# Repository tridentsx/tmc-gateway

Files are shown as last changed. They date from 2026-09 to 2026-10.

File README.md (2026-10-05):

# tmc-gateway

A PoE Ethernet- and USB-attached GPIB instrument gateway: one small board,
plugged directly into an instrument's IEEE-488 connector, that exposes it to
the network and to USB simultaneously.

## What it does

One RP2354A-based adapter per GPIB instrument, acting as that instrument's
GPIB System Controller and Controller-in-Charge, reachable over:

- **[HiSLIP][hislip]** (IVI-6.1) over Ethernet/PoE, TCP port 4880
- **USBTMC** and its **USB488** subclass over USB
- Raw SCPI over TCP port 5025 (planned; not yet built)

The central architectural rule, carried over from the design specification:

> HiSLIP, USBTMC/USB488, raw SCPI, and any future management interface never
> manipulate GPIB pins directly. They submit operations to one serialized
> GPIB engine.

That engine is [`gpib.Instrument`](gpib/instrument.go) — see
[Software](#software) below.

## Hardware

| | |
|---|---|
| MCU | RP2354A (RP2350 family, 2 MB integrated flash), QFN-60 |
| Ethernet | WIZnet W5500 (SPI) |
| PoE | DP9900LPB isolated PD module, IEEE 802.3af, with a USB-C alternate power path (§30.1) |
| GPIB transceivers | TI SN75160B (data bus) + SN75161B (management bus) |
| GPIB connector | 24-pin IEEE-488, NorComp 112-024-113R001 |
| USB | USB-C (USBTMC/USB488, plus alternate power input) |

Board is 62×68 mm, 4 copper layers. Schematic is complete and verified —
confirmed by actually running the checks below, not just citing an old note:
`scripts/netlist-check.py` reports **124 checks, 0 failures**; ERC reports 3
`pin_not_driven` errors, all on W5500 (`U2`) SPI inputs (`SCS`/`SCLK`/`MOSI`)
flagged because the driving RP2354A pins are bidirectional across a
hierarchical sheet link — a severity-policy question, not a wiring defect.
PCB has all 93 footprints placed but is **not yet routed**.

- [`docs/design-spec.md`](docs/design-spec.md) — the master design
  specification. One document by design: Part I is the HiSLIP library
  ([tridentsx/hislip][hislip], developed in that separate repository), Part
  II is this hardware, Part III is this firmware, and Parts IV–VII
  (milestones, acceptance criteria, design decisions, risk register) span
  all three. Source comments in `hislip` cite it by section, e.g. "§5.1".
- [`docs/netlist-spec.md`](docs/netlist-spec.md) / [`docs/netlist-spec.nets`](docs/netlist-spec.nets) —
  the canonical net table `scripts/netlist-check.py` verifies the exported
  schematic netlist against.
- [`docs/rp2354a-pinmap.md`](docs/rp2354a-pinmap.md) — the RP2354A GPIO
  assignment: 8 data lines and the DAV/NDAC/NRFD handshake lines suggested
  for PIO, ATN/SRQ/REN/IFC/EOI as plain GPIO, SPI0 to the W5500.

## Software

```text
gpib/            the Instrument abstraction every front end drives (no
                  firmware, no bus driver -- just the interface)
hislipfront/      adapts gpib.Instrument to tridentsx/hislip's server.Device
usbtmcfront/      adapts gpib.Instrument to USBTMC/USB488 Bulk-OUT messages
usbep/            portable, unit-tested USB packet reassembly (host->device)
                  and chunking (device->host) usbtmcfront's messages ride on
cmd/firmware/     the real (skeleton) RP2354A firmware entry point --
                  tinygo-only, gated by the "tinygo" build tag
cmd/tinygocheck/  not firmware -- exists so `just tinygo` has a real main
                  package to build and link, exercising gpib/hislipfront/
                  usbtmcfront together under mainline go's dependency
                  graph but a real tinygo build
cmd/debugconsole/ host-side only (plain go build, no tinygo tag): a
                  terminal UI for cmd/firmware's CDC debug console
```

`gpib.Instrument` is deliberately not a copy of `hislip/server.Device`,
despite both stating the identical "must not know it's GPIB" principle:
`RemoteEnable`, `LocalLockout`, and `GoToLocal` are three separate methods
here, because USB488's own control requests (`REN_CONTROL`, `GO_TO_LOCAL`,
`LOCAL_LOCKOUT`) are three separate requests, not HiSLIP's one combined
`RemoteLocal(mode)` call. Both front ends translate onto the same granular
primitives instead of one needing to reconstruct a combined mode it never
actually received.

### Status

| Piece | State |
|---|---|
| `gpib.Instrument` abstraction | Defined |
| `hislipfront` (HiSLIP → `gpib.Instrument`) | Implemented, unit-tested |
| `usbtmcfront` (USBTMC/USB488 → `gpib.Instrument`) | Core Bulk-OUT dispatch implemented, unit-tested — see scope below |
| `usbep` (USB packet reassembly/chunking) | Implemented, unit-tested — real edge cases (exact-multiple-of-packet-size, empty message, byte-at-a-time feed) |
| `cmd/firmware` (real USB descriptor + endpoint wiring) | Skeleton exists and **actually builds**: `tinygo build -target=pico2` produces a real, well-formed flashable UF2. Backed by a stub `gpib.Instrument` — no real GPIB bus driver yet. **Verified on real hardware** (a W5500-EVB-Pico2, RP2350): descriptor enumerates exactly as designed, and a real USBTMC `RequestDevDepMsgIn` round trip over EP3 OUT/IN produces a correctly encoded response — see below. |
| GPIB bus driver (the concrete `gpib.Instrument`) | Not started |
| Raw SCPI front end | Not started |

Real, load-bearing constraints found by reading TinyGo 0.42.0's actual
`machine/usb` source (not assumed): it hardcodes a **maximum of 3 USB
interfaces total** (a fixed-size array, not a slice), so a USB CDC debug
console (2 interfaces) plus USBTMC (1) exactly fills the budget, with no
room left for anything else on this port. Its outgoing-transfer path does
not itself split a payload larger than one packet across multiple
packets — that's what `usbep.ChunkSender` and `cmd/firmware`'s
`TxHandler` callback do, deliberately, rather than being handled for free
by the framework.

`usbtmcfront`'s stated scope, deliberately not (yet) covered:

- Works on one already-reassembled logical USBTMC message, not raw USB
  transfers — splitting a message across several USB packets and the
  alignment padding USBTMC requires between messages is a transport-framing
  concern for whatever wires it to a real USB endpoint later, the same
  split `hislip/server`'s `Stream` abstraction makes.
- TermChar-based early read termination is decoded but ignored.
- Every control-transfer-based USBTMC/USB488 request — `GET_CAPABILITIES`,
  `INITIATE_CLEAR`, `READ_STATUS_BYTE`, `REN_CONTROL`, `GO_TO_LOCAL`,
  `LOCAL_LOCKOUT`, the abort requests — is not implemented at all; only the
  three Bulk-OUT message types (`DevDepMsgOut`, `RequestDevDepMsgIn`,
  `Trigger`) are.

One real, non-mechanical piece of protocol work is still open before the
bus driver can start: **the real IEEE-488.1 three-wire handshake and
ATN-based addressing.** Nothing here has been verified against real GPIB
hardware yet; treat any bus-timing claim in this repo's history as reasoned
from the spec text, not measured.

### Real-hardware findings (`cmd/firmware`, W5500-EVB-Pico2 / RP2350)

Confirmed by actually flashing and exercising the board, not just building
for it:

- The composed descriptor (CDC debug console + USBTMC/USB488) enumerates
  exactly as designed: 3 interfaces, correct classes (CDC `0x02/0x02/0x01`
  + `0x0A/0x00/0x00`, USBTMC/USB488 `0xFE/0x03/0x01`), correct endpoint
  addresses (`0x03`/`0x83` for the shared USBTMC bulk endpoint).
- A real `RequestDevDepMsgIn` Bulk-OUT write followed by a Bulk-IN read,
  issued from the host with [go-usb][go-usb], round-trips correctly end to
  end through `usbtmcRxHandler` → `usbep.Reassembler` → `usbtmcfront.Handler`
  → `usbep.ChunkSender` → `usbtmcTxHandler`.
- Two real firmware bugs were found and fixed this way, both specific to
  running inside TinyGo's bare-metal USB interrupt handlers, not to the
  protocol logic itself:
  1. `main()` called `machine.EnableCDC` a second time. TinyGo's own
     runtime (`initUSB`, which runs before `main`) already calls it via
     `machine/usb/cdc.EnableUSBCDC` with working handlers; the redundant
     call overwrote them with no-op stubs, silently breaking the debug
     console.
  2. `usbtmcRxHandler` called `println`, `reasm.Feed`, `append`, and
     `usbtmcfront.Handler.HandleBulkOut` directly — all either blocking or
     allocating — from inside a USB interrupt handler. TinyGo's bare-metal
     allocator is not interrupt-safe, so this corrupted state the moment a
     real bulk transfer arrived. The handler now only copies the raw
     packet into a fixed-size ring with a plain array copy (no allocation,
     no blocking); reassembly, dispatch, and response encoding all run in
     the main loop instead, which drains that ring alongside a lightweight
     event log and a heartbeat print, giving an unambiguous liveness signal
     during this kind of debugging.

Built for the *next* real-hardware session, not just this one:
`cmd/firmware`'s CDC console is now interactive (`help`/`version`/
`stats`/`last`/`clear`/`uptime`/`ping`), backed by persistent counters
(packets in, messages reassembled, responses sent, ring overflows, TX
failures) and a bounded hex dump of the last message/response — confirmed
working on real hardware, including the counters incrementing correctly
across a real bulk transfer and `last` showing the exact bytes exchanged.
See `cmd/firmware/debug.go`. `version` reports the exact git commit (plus
`-dirty` if built from an uncommitted tree) and build time, baked in by
`just firmware`'s `-ldflags -X`, so it's possible to confirm which build
is actually running on a given board.

**`cmd/debugconsole`** is the host-side companion: a terminal UI
(`go run ./cmd/debugconsole`, or `just debugconsole`) with a menu of the
commands above plus a free-text box for anything not in that list yet,
so a real-hardware session doesn't mean hand-typing into `screen`/
`picocom`/a pyserial script. Plain `go build`, no `tinygo` tag — runs on
the development machine against an already-flashed, already-connected
board, never on the RP2350 itself.

## Related repositories

- [tridentsx/hislip][hislip] — the HiSLIP protocol/server/client library
  this board's Ethernet-side front end is built on. Intended, once
  finished, to be offered to the `gotmc` organisation.
- [tridentsx/usbtmc][usbtmc] — a fork of [gotmc/usbtmc][gotmc-usbtmc]
  adding a driver backed by [tridentsx/go-usb][go-usb] (no cgo, no
  libusb), intended to be contributed upstream. Its new `wire` subpackage
  is the USBTMC wire-format vocabulary this board's USB-side front end
  will build on.
- [tridentsx/go-usb][go-usb] — the pure-Go USB backend behind the
  `usbtmc` driver above.

## Building what exists today

```sh
go build ./...
go vet ./...
go test ./...
```

```sh
kicad-cli sch export netlist --format kicadsexpr -o build/adapter.net hardware/adapter.kicad_sch
python3 scripts/netlist-check.py docs/netlist-spec.nets build/adapter.net   # expect 131/0
kicad-cli sch erc --severity-error -o /tmp/erc.rpt hardware/adapter.kicad_sch
```

[hislip]: https://github.com/tridentsx/hislip
[usbtmc]: https://github.com/tridentsx/usbtmc
[gotmc-usbtmc]: https://github.com/gotmc/usbtmc
[go-usb]: https://github.com/tridentsx/go-usb

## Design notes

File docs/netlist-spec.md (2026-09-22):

# Netlist Specification: PoE-to-GPIB Adapter

**Status:** Draft — Revision 2 (from-scratch discrete board)
**Date:** 2026-09-21
**Board:** GoTMC HiSLIP PoE-to-GPIB adapter — discrete RP2354A + W5500
**Parent document:** [design-spec.md](design-spec.md), Revision 3, Part II (§25–§33), §41, §64.

---

## 0. Revision 2 changes and divergence from design-spec

Revision 1 specified the board as a carrier for the WIZnet **W5500-EVB-Pico2 module**.
That module is retained only for firmware/protocol development; the production
board is **built from discrete silicon**. This revision replaces the module with a
discrete RP2354A + W5500 design and, in doing so, resolves the supply-sequencing
element differently. The changes below **diverge from design-spec.md Revision 3**
and are proposed for adoption in a design-spec **Revision 4** (§10):

1. **Module → discrete.** design-spec.md §26.1 and stable-decision 11 name the
   W5500-EVB-Pico2 as the platform. Here it is the *development* platform only;
   the product is discrete RP2354A + W5500. The GPIO map, the GPIB physical layer
   and every requirement `R-HW-*` are preserved.
2. **RP2350 → RP2354A.** The QFN-60 RP2354A is pin-identical to the RP2350A but
   adds **2 MB internal stacked flash**, so the external QSPI flash IC, its
   decoupling and the six QSPI nets are removed (RP "Hardware design with RP2350",
   §3: *use RP2354 by omitting the onboard flash and R10*). RP2354 ships on the
   **A4 stepping, which fixes erratum RP2350-E9**; this relaxes `R-HW-030`/`R-HW-031`
   (the Bank-0 input-latch hazard) — external bias is retained for direction
   control, not for E9.
3. **Gating element (decision 1) → all-discrete PG-driven gate.** The load-switch
   IC + supervisor of Revision 1 (TPS22918 + TPS3839) become a **P-FET high-side
   switch + N-FET level-shift driven by a 3V3-good signal** (§3.1). Because the
   board now owns its 3.3 V regulator, "3V3-good" comes from a supervisor on that
   rail rather than a bolt-on watching a module output.
4. **Assembly constraints.** Hand-soldered v1: **passives 0805 minimum**; ICs in
   QFN-60/LQFP/SOIC/SOT/SOT-223 (all hand-solderable). Every BOM line carries an
   **LCSC part number** so symbols/footprints pull via `easyeda2kicad` and the
   same BOM feeds a later JLCPCB PCBA revision.

---

## 1. Purpose and scope

The electrical specification of the discrete adapter board: component list with
LCSC part numbers, the nets, the values that make the board safe, and the trace
from each `R-HW-010`..`R-HW-065` to the parts and nets that implement it.

**Specification depth.** The *decision and safety-critical* subsystems — the
transceiver-rail gate (§3.1), the GPIB safe-state bias (§3.2), the GPIB signal
path, the RP2354↔transceiver GPIO map, the power rails, and the IEEE-488
connector — are specified **pin-precisely** and are machine-checked (§9). The
*standard* MCU and Ethernet support subsystems are specified as **component
blocks with their key nets**, to be entered from two proven references rather than
re-derived pin-by-pin:

- **RP2354A:** Raspberry Pi *"Hardware design with RP2350"* + the **RP2350A Minimal
  KiCad design** (omit flash for RP2354).
- **W5500:** the WIZnet **W5500 datasheet reference schematic (Figure 3)** and a
  W5500 KiCad reference design.

This split matches the parent's own latitude (design-spec.md §31 leaves magnetics/
grounding to EMC, §32 makes protection footprints optional) and the build flow:
the standard subsystems are pulled as reference blocks, the safety-critical parts
are authored here and verified.

RFC 2119 keywords per design-spec.md §1.1. This document defines no new `R-HW-*`
identifiers; it references and implements those of design-spec.md §26–§28.

---

## 2. Architecture

```text
        RJ45 (PoE MagJack J2, 802.3af)
        │  data pairs         centre taps + spare pairs
        │                     │
   Ethernet magnetics    ┌────┴─────┐
        │                │ WIZPoE-P1 │ M1  (isolated 802.3af PD)
   TXOP/TXON/RXIP/RXIN   └────┬─────┘
        │                     │ isolated 5 V
      W5500 U2  ◄── SPI ──►  +5V_POE ───┬─────────────────────┐
        │  (GPIO16-21)                   │                     │
        │                          U5 LDO 5V→3V3          Q1 P-FET gate
      RP2354A U1                        │                (on when 3V3 good)
        │  GPIO0-15 (GPIB)          +3V3 ─┬─ U6 supervisor      │
        │  GPIO26/27 (TE/DC)              │   └── 3V3-good ──► Q2 ──► Q1 gate
        │  USB (J3)                  (IOVDD, W5500, bias)       │
        │                                                  +5V_XCVR
   ┌────┴──────┐                                           │  (gated)
   │           │                                    ┌──────┴──────┐
 U3 SN75160B  U4 SN75161B  ◄── VCC = +5V_XCVR ──────┤             │
 (DIO1-8)     (ATN…NRFD)                            (off until 3V3 good)
   └────┬──────┘
     IEEE-488 J1 → instrument
```

Two rails: `+5V_POE` (always present when powered) and `+3V3` (from U5).
`+5V_XCVR` is `+5V_POE` gated by Q1 on 3V3-good. The adapter is permanently the
GPIB System Controller (design-spec.md §26.5).

---

## 3. Decisions resolved

### 3.1 Decision 1 — supply sequencing, all-discrete (`R-HW-020`..`R-HW-022`, `R-HW-044`)

**Gate the transceiver 5 V rail on 3V3-good, with discrete parts.** Same hazard as
Revision 1: the RP2354 Fault-Tolerant pads tolerate 5.5 V **only while IOVDD is at
3.3 V** (RP2350 datasheet §14.9, `VPIN_FT`). `+3V3`/IOVDD comes up after `+5V_POE`,
so the transceivers must not be powered until `+3V3` is good. The SN75160B/SN75161B
present *"No Loading of Bus When Device Is Powered Down (VCC = 0)"* (SLLS004B/005B),
so an unpowered transceiver also satisfies the primary safe-bus requirement
(`R-HW-044`).

Circuit:

```text
            +5V_POE ──┬───────────────[Q1 S]  AO3401 P-FET
                      │                 │
                    R_G1 100k          [Q1 D]──► +5V_XCVR  (U3/U4 VCC)
                      │                 │
            gate node ┴───────┬─────────┘
                      │      C_G 100nF (soft-start / inrush, R-HW-051)
                    [Q2 D]  2N7002 N-FET
                      │
            3V3-good ─[Q2 G]      [Q2 S]──GND
                │      │
              (U6)    R_G2 100k ──GND   (fail-safe: Q2 off when 3V3-good undriven)
```

| Ref | Part (LCSC) | Role |
|---|---|---|
| **U5** | LDO 5V→3.3V, AP2114H-3.3TRG1, SOT-223 (**C150716**); alt AMS1117-3.3 (**C6186**) | `+5V_POE → +3V3`, ≥1 A ≫ the ~180 mA load (§3.3) |
| **U6** | Supervisor **TPS3839G33DBZR**, SOT-23-3 (**C485802** ✔), `VIT-` = 3.003/**3.08**/3.126 V, `Vhys` 31 mV, **push-pull** active-low RESET | Emits **3V3-good** (RESET high when +3V3 ≥ threshold) |
| **Q1** | AO3401 P-FET, SOT-23 (**C15127**), −30 V, `Vgs(th)` ≈ −1.1 V | High-side switch `+5V_POE → +5V_XCVR` |
| **Q2** | 2N7002 N-FET, SOT-23 (**C8545**) | Level-shifts 3V3-good to the 5 V-referenced Q1 gate; allows full turn-off |
| **R_G1** | 100 kΩ, gate→+5V_POE | Default **off** (Q1 gate pulled to source) |
| **R_G2** | 100 kΩ, Q2 gate→GND | Fail-safe **off** when U6 is unpowered/high-Z |
| **C_G** | 100 nF, gate→+5V_POE (with R_G1) | Controlled turn-on ~10 µs–ms band, inrush limit (`R-HW-051`) |

Chain: **+3V3 ≥ 3.08 V → U6 RESET high → Q2 on → Q1 gate pulled low → Q1 on →
+5V_XCVR live.** When +3V3 is absent U6 is unpowered, `R_G2` holds Q2 off, `R_G1`
holds Q1 off, `+5V_XCVR` is dead — the transceivers cannot drive the FT pads or
the bus. This is the sequencing `R-HW-020` requires, built from a P-FET the way
you asked, with the "3V3-good" threshold (not mere presence) coming from U6.

**U6 = TPS3839G33DBZR (C485802), verified against SBVS193D.** Its `RESET` is
**push-pull**, so `PG_3V3` needs no pull-up and `R_G2` remains the sole fail-safe;
an open-drain supervisor would have required a pull-up whose rail choice is itself
a hazard (a pull-up to +5V would assert 3V3-good with no +3V3 present). `VIT-` =
3.003 / 3.08 / 3.126 V against the AP2114H's ±1.5 % band (3.25–3.35 V) leaves
≈124 mV between `VIT-`max and the rail's minimum, so the gate cannot chatter.

**Defect found while drawing the schematic (2026-09-21): `C_G` must return to
+5V_POE, not to GND.** The machine-readable table in `docs/netlist-spec.nets`
listed `C_G.2` on `GND` while the row above puts C_G "gate→+5V_POE". Those are
not interchangeable. A gate-to-GND capacitor holds the gate near 0 V while
`+5V_POE` rises, so `Vgs` follows the rail down to about −5 V and **Q1 turns on**
during the ramp — powering the transceivers with IOVDD absent, the exact
condition `R-HW-020` exists to prevent. Referenced to the source instead, C_G
holds `Vgs ≈ 0` (off) through the rail's rise and, with `R_G1`, sets the
turn-on ramp. The schematic follows this row; the net table has been corrected
to match, and `scripts/netlist-check.py` now fails if C_G is moved back.

**Consequence for the boot sequence (§41, `R-FW-110`):** the TPS3839 holds RESET
asserted for a further **≈200 ms** after +3V3 crosses `VIT- + Vhys`, so
`+5V_XCVR` — and therefore U3/U4 — is unpowered for roughly the first 200 ms of
board life. Firmware MUST NOT assume the transceivers are powered at reset; this
strengthens rather than weakens `R-HW-020`, but it is a timing fact the firmware
bring-up has to expect.

Why not a single integrated-PG LDO: the clean LCSC part (LM9076, LDO + delayed
reset) is rated **150 mA**, below the ~180 mA the W5500-dominated 3.3 V rail draws,
so a ≥1 A LDO plus a separate supervisor is used. `VIT-` = 3.0–3.08 V is high
enough that IOVDD is effectively 3.3 V for the FT precondition, low enough to
clear the LDO's regulation band. Compatible with the boot sequence (design-spec.md
§41): hardware enforces step 1 before firmware runs (`R-FW-110`).

### 3.2 Decision 2 — safe bus state (`R-HW-040`..`R-HW-044`), unchanged from Rev 1

The SN75161B direction table (SLLS005B): ATN/IFC/REN follow **DC** (driven onto the
bus only when DC = L); DAV/NDAC/NRFD follow **TE**. RP2354 pads come up
high-impedance, so TE and DC are biased externally; the RP2354 A4 stepping fixes
E9, but external bias is still required to define direction when the MCU is not
driving.

**Safe state: `TE = L`, `DC = H`** → SN75160B DIO high-impedance, ATN/IFC/REN
received (not driven). SRQ, NDAC, NRFD are the only lines the SN75161B drives in
this state; SRQ is de-asserted by bias, NDAC/NRFD settle to the benign
not-ready/not-accepted hold (no transfer without a DAV strobe, and DAV is a
receiver here).

| Net | Bias | Result |
|---|---|---|
| `TE`  (U1 GPIO26) | `R_TE` 10 kΩ **→ GND** | TE = L: nothing drives data or DAV |
| `DC`  (U1 GPIO27) | `R_DC` 10 kΩ **→ +3V3** | DC = H: ATN/IFC/REN receive |
| `ATN_T` (GPIO8) | `R_ATN` 10 kΩ **→ +3V3** | de-assert if DC ever = L with MCU idle (`R-HW-041`) |
| `REN_T` (GPIO10)  | `R_REN` 10 kΩ **→ +3V3** | `R-HW-041` |
| `IFC_T` (GPIO11)  | `R_IFC` 10 kΩ **→ +3V3** | `R-HW-041` |
| `SRQ_T` (GPIO9) | `R_SRQ` 10 kΩ **→ +3V3** | de-assert the SRQ driven when DC = H |

**Rail discipline (invariant):** every bias references `+3V3` or `GND`, **never
`+5V`**. TE/DC land on GPIO26/27, which are not fault-tolerant, so a 5 V pull-up is
forbidden (design-spec.md §64); the FT-pin pull-ups also stay on +3V3 so no 5 V is
injected during the IOVDD-absent window.

### 3.3 Decision 3 — power budget (`R-HW-050`..`R-HW-053`)

**3.3 V rail (from U5):**

| Load | Current | Source |
|---|---:|---|
| W5500 @100 Mbit/s TX | 132 mA | W5500 datasheet |
| RP2354A dual-core @150 MHz + PIO + SPI + IO | 30 mA | RP2350 datasheet Table 1446 + margin |
| Board housekeeping (status LED, U6, crystals) | 15 mA | est. |
| Safe-state bias (DC + ATN/REN/IFC/SRQ + CFG ≈ 6 × 0.33 mA) | 2 mA | computed |
| **+3V3 subtotal** | **≈ 180 mA** → 0.59 W | |

**U5 dissipation:** (5 − 3.3) × 0.18 ≈ **0.31 W** in the LDO — fine in SOT-223, but
it is the board's hot spot and is included in the thermal check (`R-HW-053`).

**5 V transceiver rail `+5V_XCVR`** (gated): SN75160B `ICC` 110 mA + SN75161B `ICC`
110 mA + bus-termination worst case ~30 mA ≈ **250 mA → 1.25 W** (SLLS004B/005B).

**Total on `+5V_POE`:** module-less, so: U5 input (0.59 W ÷ ~0.9 ≈ 0.15 A at 5 V
after LDO — an LDO is ~66 % efficient here, so ≈ 0.18 A) + `+5V_XCVR` 0.25 A +
housekeeping ≈ **≈ 0.44 A → 2.2 W**, +25 % margin ≈ **0.55 A → 2.75 W**.

**Against the sources:** WIZPoE-P1 rated 5 V / **8 W typ (≈ 1.6 A)** → load is
28–34 %, margin > 3×. 802.3af guarantees **12.95 W at the PD**; input ≈ 2.2 W ÷ 0.80
≈ **2.75 W** typical (≈ 3.4 W worst-case) → **Class 1 (≤ 3.84 W)**, margin > 3×.
M1's class is programmable, so the board can declare Class 1 and a PSE reserves
only that much rather than a module's full rating.

**Inrush / bulk (`R-HW-051`):** `C_BULK` 47 µF on `+5V_POE` (hold-up through the
`+5V_XCVR` turn-on step); `+5V_XCVR` local bulk 2 × 4.7 µF + 2 × 100 nF, charged
through the `R_G1`·`C_G` gate ramp on Q1 (soft-start), inrush a few tens of mA.
`R-HW-052` replaces these with measured figures on the prototype.

---

## 4. Component list (BOM)

Passives are **0805 minimum**, X7R/C0G, 1 % (R) / 10 % (C) unless noted. LCSC
numbers marked *(verify)* are the best current candidate to confirm on LCSC before
release; representative 0805 basic-part numbers are given for common values.

### 4.1 Active / key components

| Ref | Part | Package | LCSC | Function |
|---|---|---|---|---|
| **U1** | Raspberry Pi **RP2354A** | QFN-60 | **C41378174** | MCU, 2 MB internal flash (no external QSPI) |
| **U2** | WIZnet **W5500** | LQFP-48 | **C32843** ✔ | Hardwired TCP/IP + 10/100 PHY |
| **U3** | TI **SN75160BDW** | SOIC-20 | *(number to source)* | GPIB data transceiver (DIO1–8). Symbol/footprint from KiCad stock: `Interface:SN75160BDW` + `Package_SO:SOIC-20W_7.5x12.8mm_P1.27mm` |
| **U4** | TI **SN75161BDW** | SOIC-20 | **C139410** ✔ | GPIB management transceiver (C139410 is the **161**, confirmed) |
| **U5** | Diodes **AP2114H-3.3TRG1** | SOT-223 | **C150716** ✔ | 5 V→3.3 V LDO, 1 A (alt AMS1117-3.3, **C6186** ✔). **Not C166063** — see §4.3 |
| **U6** | TI **TPS3839G33DBZR** (`VIT-` 3.08 V typ, push-pull) | SOT-23-3 | **C485802** ✔ | 3V3-good signal. Pins: 1 GND, 2 `RESET`, 3 VDD |
| **Q1** | Alpha&Omega **AO3401** | SOT-23 | **C15127** | P-FET high-side gate |
| **Q2** | **2N7002** | SOT-23 | **C8545** | N-FET level-shift |
| **M1** | PoE PD front-end — SDAPO **DP9900LPB-5V1.4A**, isolated PD module + DC-DC, 36–57 V in, 5 V/1.4 A (7 W) out, 1500 V I/O isolation, **programmable power class**. Bridges are **not** included — see D_BR1/D_BR2 | SMD, **21.2 × 13.9 × 8.0 mm** (verified from the part's 3D model) | **C53065982** ✔ *(specs/geometry verified; stock not verified)* | Isolated 802.3af PD → +5V_POE. Pins: 1 +VDC → +5V_POE, 2 −VDC → GND, 3 ADJ (unused), 4 VIN+, 5 VIN− ← bridge outputs. Dimension- and pin-compatible with **Silvertel Ag9905-LPB** (second source) |
| **D_BR1, D_BR2** | MCC **MB6S-TP** bridge rectifier ×2, 600 V / 0.5 A | MBS (SOIC-4), 4.7 × 4.0 × 2.5 mm | **C85619** ✔ | Rectify each pair set for M1's VIN±: D_BR1 = Alternative A (RJ45 1&2, 3&6 taps), D_BR2 = Alternative B (4&5, 7&8). ~60 mA at 48 V against a 0.5 A rating; 600 V PIV is generous over 57 V + surge |
| **J1** | **NorComp 112-024-113R001** — Centronics-24 (IEEE-488) **male**, right-angle PCB; alt FUYCONN FUY57109A | 24-way THT, 2 × 12 on 2.16 mm pitch, 4.29 mm rows, 2 × 3.1 mm holes on 46.8 mm | *(distributor; not an LCSC line)* | Instrument connector, **direct plug** into the instrument's female port. Symbol `Connector_GPIB:Conn_GPIB_L-com_CIB24SRA` (pinout is gender-independent); footprint `adapter:CONN_112-024-113R001_NRC`, **verified** — see §4.4 item 2 |
| **J2** | PoE MagJack — candidate **USAKRO DGUK411Q211DB2A1DP2** (2.5G PoE+, 4-pair, 4 × CT + VC1–VC4) | RJ45 TH int. magnetics | **C19725138** ⚠ *(pin function unconfirmed — see §4.4)* | Ethernet + PoE tap |
| **J3** | USB-C receptacle **TYPE-C-31-M-12** | 16-pin SMD | **C165948** | USB (flash + CDC diag) |
| **X1** | **12 MHz** crystal, Abracon **ABM8-272-T3** (RP-recommended), 10 pF, ≤50 Ω ESR | 3.2×2.5 mm | *(verify; LCSC 12 MHz alt)* | RP2354 clock |
| **X2** | **25 MHz** crystal (W5500), ±30 ppm | 3.2×2.5 mm | *(verify)* | W5500 clock |
| **L1** | Abracon **AOTA-B201610S3R3-101-T**, 3.3 µH, shielded, polarity dot | 0806 | *(verify)* | RP2354 core SMPS inductor |

### 4.2 Passives and discretes (0805 minimum)

**Designator convention.** KiCad treats a reference with no trailing digit as
*unannotated*, and an annotate pass in eeschema would silently rename such parts
— breaking the correspondence between the schematic and this document. Every
designator therefore carries a numeric suffix in the schematic and in
`netlist-spec.nets`: `R_TE1`, `C_G1`, `TP_5V1`, `C_U3a1`, and so on. This
section's tables name the parts without the suffix for readability; the suffixed
form is the authoritative one.

| Ref(s) | Value | LCSC (representative) | Purpose |
|---|---|---|---|
| C_BULK | 47 µF, 16 V | C2011903 ✘ *(is a 16 MHz oscillator — reselect)* | +5V_POE bulk / hold-up (`R-HW-051`) |
| C_U3a, C_U4a | 100 nF ×2 | C49678 ✔ | VCC bypass at U3/U4 |
| C_U3b, C_U4b | 4.7 µF ×2 | C1779 ✔ (0805) | +5V_XCVR local bulk |
| C6, C7, C9 | 4.7 µF ×3 | C1779 ✔ | RP2354 core reg in/out (per RP minimal) |
| C_1V2 | 4.7 µF | C1779 ✔ | W5500 1V2O (datasheet-mandated) |
| C_ANA | 10 nF | C1710 ✔ (0805) | W5500 analog cap (datasheet-mandated) |
| C_MCU × n | 100 nF each | C49678 ✔ | RP2354 IOVDD/DVDD decoupling (per RP minimal) |
| C_ETH × n | 100 nF each | C49678 ✔ | W5500 AVDD/VDD decoupling |
| C_X1a/b | 15 pF ×2 | C1644 ⚠ *(value right, **0603** — breaks the 0805 rule)* | X1 (12 MHz) load caps |
| C_X2a/b | per X2 spec | *(verify)* | X2 (25 MHz) load caps |
| C_3V3 | 1 µF | C28323 ✔ | +3V3 local bypass |
| C_LDO | 1 µF in + 1 µF out | C28323 ✔ | U5 in/out (AP2114H) |
| RSET | 12.4 kΩ 1% | C218478 ✘ *(is 287 Ω — reselect)* | W5500 EXRES1 → AGND |
| R_G1 | 100 kΩ | C149161 ✘ *(no such part — reselect)* | Q1 gate pull-up → +5V_POE |
| R_G2 | 100 kΩ | C149161 ✘ *(no such part — reselect)* | Q2 gate pull-down → GND |
| C_G | 100 nF | C49678 ✔ | Q1 gate soft-start |
| R_TE | 10 kΩ | C17414 ✔ | TE pull-down → GND (`R-HW-040`) |
| R_DC | 10 kΩ | C17414 ✔ | DC pull-up → +3V3 (`R-HW-040`) |
| R_ATN,R_REN,R_IFC,R_SRQ | 10 kΩ ×4 | C17414 ✔ | de-assert bias → +3V3 (`R-HW-040`/`041`) |
| R_CFG | 10 kΩ | C17414 ✔ | CFG (GPIO28) defined state (`R-HW-065`) |
| R_CC1, R_CC2 | 5.1 kΩ ×2 | C23186 ⚠ *(value right, **0603**)* | USB-C CC pull-downs (device role) |
| R_PE | 0 Ω (opt pad) | C17168 ⚠ *(value right, **0402**)* | U3 PE→+5V_XCVR (3-state, §29) |
| R_RUN, R_BOOT | 10 kΩ ×2 | C17414 ✔ | RUN pull-up / BOOTSEL (per RP minimal) |
| SW_RUN, SW_BOOT | tact | *(verify)* | reset / BOOTSEL buttons |
| LED1 (+R_LED) | status LED + 1 kΩ | C2286 ⚠ *(**0603** LED)* / C17513 ✔ | status LED (`R-HW-064`), on a GPIO |
| R_SH / C_SH | 0 Ω / RC (opt) | C17168 ⚠ *(**0402**)* | connector shield → chassis (§31) |
| TP_* | test pads | — | TE,DC,ATN,DAV,NRFD,NDAC,SRQ,IFC,5V,3V3,GND (§32) |

### 4.3 LCSC verification log (2026-09-21)

Every number above was queried against the EasyEDA/LCSC component API before any
symbol was pulled; `✔` means the API returned the expected manufacturer part and
an 0805-or-larger package, `⚠` the right value in a package smaller than the
§0.4 hand-assembly rule, `✘` a number that does not describe the intended part at
all. Seven of the twenty checked were wrong, so **no number in this document may
be trusted without a query** — including the ones that were never marked *(verify)*.

| Number | Spec claimed | API returned | Verdict |
|---|---|---|---|
| C41378174 | RP2354A | RP2354A, QFN-60 | ✔ |
| C32843 | W5500 | W5500, LQFP-48 | ✔ |
| C139410 | SN75161BDW (160/161 unsure) | SN75161BDW, SOIC-20 | ✔ — it is the **161** |
| C166063 | AP2114H-3.3TRG1 | **SK1117-1.5** (SHIKUES), a **1.5 V** LDO | ✘ **wrong rail** |
| C150716 | — | AP2114H-3.3TRG1 (Diodes), SOT-223 | ✔ **use this for U5** |
| C53065982 | — | DP9900LPB-5V1.4A (SDAPO), 5 V/1.4 A PD module, 21.2 × 13.9 × **8.0 mm** from its 3D model | ✔ **use this for M1** |
| C53065979 | — | DP9900MTB-5V1.8A, same footprint, 13.4 mm tall | ⚠ rejected on height |
| C53065972 | — | DP1425-5V1.8A, bridges included, single-row edge-mount SIP | ⚠ rejected: height undocumented |
| C85619 | — | MB6S-TP (MCC), 600 V/0.5 A bridge, MBS 4.7 × 4.0 mm | ✔ **use this for D_BR1/D_BR2** |
| C6186 | AMS1117-3.3 (alt) | AMS1117-3.3, SOT-223 | ✔ |
| C15127 | AO3401 | AO3401A, SOT-23 | ✔ |
| C8545 | 2N7002 | 2N7002, SOT-23 | ✔ |
| C165948 | TYPE-C-31-M-12 | TYPE-C-31-M-12 | ✔ |
| C7217089 | AR11-3757I MagJack | *not in catalogue* | ✘ |
| C485802 | — | TPS3839G33DBZR (TI), SOT-23-3, `VIT-` 3.08 V, push-pull | ✔ **use this for U6** |
| C19725138 | — | DGUK411Q211DB2A1DP2 (USAKRO), 2.5G PoE+ RJ45 TH, 22 pins | ⚠ **J2 candidate**, pinout unconfirmed |
| C49678 | 100 nF | CC0805KRX7R9BB104, 0805 | ✔ |
| C17414 | 10 kΩ | 0805W8F1002T5E, 0805 1 % | ✔ |
| C1779 | 4.7 µF | CL21A475KAQNNNE, 0805 | ✔ |
| C28323 | 1 µF | CL21B105KBFNNNE, 0805 | ✔ |
| C1710 | 10 nF | CL21B103KBANNNC, 0805 | ✔ |
| C17513 | 1 kΩ | 0805W8F1001T5E, 0805 | ✔ |
| C23186 | 5.1 kΩ | 0603WAF5101T5E, **0603** | ⚠ |
| C17168 | 0 Ω | 0402WGF0000TCE, **0402** | ⚠ |
| C1644 | 15 pF | CL10C150JB8NNNC, **0603** | ⚠ |
| C2286 | status LED | KT-0603R, **0603** | ⚠ |
| C218478 | 12.4 kΩ 1 % | ARG05FTC2870 = **287 Ω** | ✘ |
| C2011903 | 47 µF 16 V | 653L16003C2T = **16 MHz oscillator** | ✘ |
| C149161 | 100 kΩ | *not found* | ✘ |

**The C166063 error was the dangerous one.** It was recorded as confirmed, not
*(verify)*, and it would have put a **1.5 V** regulator on the rail that feeds
IOVDD, every bias network and the W5500 — the board would not run, and the
`R-HW-020` gate precondition ("+3V3 ≥ 3.08 V") could never be met. Correct part:
**C150716**.

Still to source before the BOM is releasable: U3 (SN75160BDW), J1 (IEEE-488
connector), X1/X2 (12 MHz / 25 MHz crystals), L1 (3.3 µH), C_BULK (47 µF), RSET
(12.4 kΩ 1 %), R_G1/R_G2 (100 kΩ), and 0805 replacements for the four `⚠` parts.
The schematic can be authored ahead of these: U3 has a stock KiCad symbol, J1 has
an authored one, and the rest are generic `Device:` symbols whose footprint
assignment is the only thing that waits on the number.

### 4.4 Open hardware questions (blocking the Ethernet/PoE sheet)

**1. The PD front-end is now specified: SDAPO DP9900LPB-5V1.4A (C53065982) plus
two MB6S bridges (C85619).** Revision 2 delegated the whole 802.3af
powered-device function to the WIZPoE-P1, a WIZnet accessory for WIZnet's own
boards, now withdrawn. The replacement covers every function the standard
requires of a PD, but it is worth being precise about where each one lives,
because the module's own marketing is easy to misread:

- **inside M1**: the 25 kΩ detection signature, the classification current
  signature (programmable class), inrush and operating current limit, the
  hot-swap switch, 1500 V galvanic isolation, and the 48 V → 5 V conversion;
- **outside M1, ours to provide**: the **bridge rectifiers**. The DP9900 series
  presents `VIN+`/`VIN−` as *Direct Input* pins that, per its pin table,
  "connect to the … output of the input bridge rectifiers" — i.e. the bridges
  are external. D_BR1 and D_BR2 supply them, one per pair set, so the board
  accepts Alternative A and B feeds in either polarity.

The isolation living inside M1 is not an optimisation: the IEEE-488 shell bonds
to the instrument chassis and J3 is a second external interface, so the barrier
must sit upstream of board ground.

**Why this part.** It was selected on **height**, which is what a dongle
enclosure actually constrains — not footprint area, as an earlier revision of
this section wrongly implied. Verified from the part's own 3D model at
**21.2 × 13.9 × 8.0 mm**, matching Silvertel's published 21 × 14 × 8 mm for the
equivalent Ag9900LPB. The alternatives measured or reported as: DP9900MTB
(C53065979) 21.2 × 13.9 × **13.4 mm**, same footprint, 5.4 mm taller; DP1425
(C53065972) bridges-included but a single-row edge-mount SIP whose height is
documented only as a drawing, hence unverifiable and plausibly 15–25 mm. 8.0 mm
is about the height of the IEEE-488 connector body, so M1 fits under the same lid
rather than setting it.

Being dimensionally and functionally interchangeable with **Silvertel
Ag9905-LPB** gives a second source, which matters on a board that already
carries an EOL risk for U3/U4 (design-spec.md §67, R24).

7 W against the §3.3 load of 2.75 W is 2.5× margin, and the programmable class
means the board can declare Class 1 rather than reserving a PSE's full budget.

**The documented path to smaller and cheaper** is MPS **MP8017**: an 802.3af PD
interface (detection, classification, inrush and operating current limit, 100 V
hot-swap MOSFET) *plus* an active-clamp primary-side-regulation flyback
controller in a QFN-19 3 × 4 mm, with an MPS 5 V reference design
(EVL8017-L-00B). It is the right answer for a volume revision or if 8 mm is ever
too tall, at the cost of owning the transformer selection, the isolation-barrier
layout and the EMC — risk that buys nothing on a v1 whose purpose is proving the
protocol stack.

**Stock is unverified** for both M1 and the bridges: specifications, geometry and
pinouts were read from datasheets, the LCSC/EasyEDA catalogue and the parts' own
3D models, none of which report inventory. Confirm availability before release.

**2. J1's gender is settled: male, and the adapter is a direct-plug dongle.**
J1 is a **FUYCONN FUY57109A**, Centronics-24 male, right-angle PCB mount, which
plugs straight into the instrument's female GPIB port — the form the original
specification intended and the one commercial GPIB-Ethernet adapters take.

Two consequences follow.

*The vendored footprint cannot be used.* `gpib-kicad-library` supplies L-com
**female** receptacles only. Male and female pad numbering are mirror images, so
building on the female pattern would put every DIO line on the wrong pin — the
one error on this sheet that produces a board which looks right and is
electrically scrambled. J1's footprint is therefore **deliberately unassigned**
until FUYCONN's PCB drawing for this part is in hand. The symbol is unaffected:
the IEEE-488 pinout is gender-independent, and it was cross-checked against §5.4
pin for pin.

*Height is the binding enclosure constraint.* A dongle hangs off the instrument's
port, so the lid clearance is set by the tallest part, not by board area. This is
what selected the 8.0 mm DP9900LPB over the 13.4 mm MTB in item 1.

**J1's footprint is now resolved: `adapter:CONN_112-024-113R001_NRC`.** The part is
a **NorComp 112-024-113R001**, the male alternate this specification already
named, and its vendor-supplied KiCad footprint was measured before adoption:

- 24 through-hole pads, 0.99 mm drill, **pins 1–12 on one row and 13–24 on the
  other** — the IEEE-488 row split, not a header's alternating order;
- **2.16 mm** pitch along each row, rows **4.29 mm** apart;
- two non-plated **3.1 mm** mounting holes at x = −11.52 and +35.28, a
  **46.8 mm** span;
- courtyard present; no 3D model supplied.

Those numbers agree with the vendored L-com female footprint, and the two are
**mirror images** of each other: the NorComp male runs pin 1 → 12 in increasing x
with holes at −11.52/+35.28, the L-com female runs 1 → 12 in decreasing x with
holes at −35.28/+11.52. Two vendors, two independently sourced files, agreeing on
the grid and differing exactly by the mirror the gender change predicts. That is
the check that the earlier revision of this section said was required, and it is
now satisfied by measurement rather than assumption.

The generic `PinHeader_2x12_P2.54mm_Horizontal` placeholder that occupied this
slot has been replaced; nothing in the design references it any more.

FUYCONN FUY57109A remains recorded as the alternate, but **its footprint has not
been verified** — the vendor's PCB drawing was not obtainable — so substituting
it requires repeating the measurement above.

**3. J2 centre-tap mapping — CLOSED 2026-09-22 by documentation.**

Resolved from the connector's own datasheet (LCSC C19725138, Dongguan Usakro,
sheet 3) and the WIZnet WIZPoE-P1 datasheet; no ring-out needed.

The connector drawing labels its two columns "PCB SIDE TO PHY" and "CABLE SIDE",
and the cable side carries `J1 TX1+` .. `J8 TX4-`, i.e. the eight RJ45 contacts.
The turns-ratio notes give every transformer as `1CT:1CT`, so both windings have
centre taps: the four `CT` pins (1, 6, 7, 12) are the **PHY-side** taps and
`VC1`-`VC4` (13-16) are the **cable-side** taps, which is where PoE is extracted.
Note 8 confirms the part is 802.3at magnetics "for PSE or PD applications", rated
720 mA / 57 V DC continuous.

The WIZPoE-P1 datasheet pin table fixes the Alternative mapping outright:

| Module pin | Connects to the centre tap of | Alternative |
|---|---|---|
| `VC1 (+)` | the pair on RJ45 **1 & 2** | A |
| `VC1 (-)` | the pair on RJ45 **3 & 6** | A |
| `VC2 (+)` | the pair on RJ45 **4 & 5** | B |
| `VC2 (-)` | the pair on RJ45 **7 & 8** | B |

each "not polarity sensitive" and feeding the +/- of an input bridge rectifier.
This is why `D_BR1`/`D_BR2` exist and why `POE_VIN_N` is not ground: neither the
Alternative nor the polarity is known in advance. Our `POE_TAP_A1/A2` therefore
take `VC1`/`VC2` and `POE_TAP_B1/B2` take `VC3`/`VC4`, as wired.

The Bob Smith network (`4*22nF`, `4*75R`, `1000pF/2kV` to `SHIELD`) is internal to
this connector - confirmed against the drawing - so no external termination or
shield capacitor is fitted. The series 22 nF per tap is what stops the two
pair-sets being DC-coupled through the common 75 R node, which is what makes the
`VC` pins usable for PoE at all.

**This is convergent evidence, not the part's own datasheet**, so it is not yet
sufficient to wire 48 V. Two things remain unproven: the `CT`/`VC` split itself,
and *which* `VC` belongs to *which* RJ45 pair — the latter matters because each
bridge must see the two taps of one Alternative (A = pairs 1&2 and 3&6, B = pairs
4&5 and 7&8). Mixing a pair-set across bridges is a wiring defect.

**Ring-out procedure (decisive, needs one sample and an ohmmeter).** Each tap sits
at the electrical centre of one transformer winding, so it reads a fraction of an
ohm to *both* ends of that winding and open to the other side of the barrier:

- a **cable-side** tap reads ≈0.5–2 Ω to both RJ45 contacts of its pair (e.g.
  contacts 1 and 2) and open to that pair's `TD±` pins;
- a **PHY-side** tap reads ≈0.5–2 Ω to both `TD+` and `TD−` of its pair and open
  to the RJ45 contacts.

The same measurement also yields the pair mapping, since it identifies which RJ45
contacts each tap belongs to. Record the result here before the Ethernet sheet is
drawn.

**Safety rule regardless of outcome:** the PHY-side taps must never connect to the
PoE feed. They sit on the isolated side referenced to board ground, and bridging
them to the cable-side taps would short across the isolation barrier that M1
provides — defeating the property that keeps 48 V off the instrument chassis
through the IEEE-488 shell.

One more property of this jack worth carrying forward: it is a 4-pair 2.5G part
while the W5500 is 10/100. The extra pairs are harmless and in fact allow both
Alternative A and B to be tapped, but the magnetics' open-circuit inductance
should be checked against the W5500's requirement when §5.6 is entered.

---

### 4.5 Silent-failure modes observed in KiCad 10 / Konnect (2026-09-22)

Three defects in this session were invisible in the schematic editor's normal
feedback and were caught only by an explicit check. Each is a class of mistake
that produces a plausible-looking sheet and a wrong netlist, so each is recorded
with the check that detects it.

**1. Wires that miss sheet pins by a grid snap.** `import_sheet_pins` places
pins at half-grid positions (x = 150.00, y = 42.54), while wire endpoints are
snapped to the 1.27 mm grid. A wire drawn to a pin's exact coordinates therefore
lands at (149.86, 41.91) and does not connect. Nothing complains: the wires are
drawn, they simply conduct nothing, and the two sheets stay on separate nets with
identical net names. Detected by `validate_wire_connections` (36 floating
endpoints) and by two nets named `TE` in one exported netlist. Fixed by placing
each sheet's origin on the 1.27 mm grid, which makes every pin grid-aligned
because the pin offsets are multiples of 2.54 mm.

**2. Sheet pins outside the sheet outline are silently merged.** `import_sheet_pins`
stacks new pins below the existing ones without growing the sheet box. Six SPI
pins imported onto a 55 mm-tall block put the last three at y = 176.53, 179.07
and 181.61 against a bottom edge at 175.65. KiCad's netlister collapsed all
three into one net: `ETH_MOSI` and `ETH_RSTn` disappeared and `ETH_INTn` carried
GPIO19, GPIO20 and GPIO21 together — three SPI signals shorted. Konnect's own
connectivity model disagreed with KiCad throughout, reporting the three nets as
correctly separate, so the schematic *looked* right from inside the tool that
drew it. Detected by the netlist gate. Fixed by enlarging the sheet block to
contain every pin. **Check pin extents against the block after every
`import_sheet_pins` call.**

**3. Duplicate `#PWR` designators across sheets.** `add_power_symbol` numbers
`#PWR` references per sheet, so a power symbol added to a second sheet reuses
`#PWR001`. The only symptom is `kicad-cli`'s generic "schematic has annotation
errors" warning on the *root* export; each sheet exports cleanly on its own, ERC
reports nothing, and `annotate_schematic` reports zero unannotated symbols
because it does not detect duplicates spread across sheets. Ruled out before
finding it: unannotated instances, reference-prefix mismatches (confirmed
irrelevant by aligning every prefix on a scratch copy — the warning persisted),
and malformed instance paths (the `/<root-uuid>/<sheet-uuid>` form is correct).
Located by bisection: removing either of two sheets cleared the warning, which
is the signature of a duplicate pair. Detect with a cross-sheet scan of
`(reference "...")` outside the `lib_symbols` block; renumber the later sheet's
symbols.

## 5. Net list

Decision/safety subsystems are pin-precise; MCU/ETH support blocks cite their
reference. Pins are `REF.pin`; U1/U2 signal pins are named by function/GPIO as they
appear in the pulled `easyeda2kicad` symbols.

### 5.1 Power and gate nets (pin-precise)

| Net | Members | Safety |
|---|---|---|
| `+5V_POE` | M1.OUT, U5.IN, Q1.S, R_G1.a, C_BULK.+, C_LDOin.+, TP_5V | WIZPoE-P1 output |
| `+3V3` | U5.OUT, U1.IOVDD(×n), U1.VREG_VIN, U2.AVDD/VDD(×n), U6.VDD, RSET pull side n/a, R_DC.a, R_ATN.a, R_REN.a, R_IFC.a, R_SRQ.a, R_CFG.a, R_RUN.a, C_3V3.+, C_LDOout.+, all C_MCU/C_ETH.+, TP_3V3 | IOVDD; **bias reference — never +5 V** |
| `+5V_XCVR` | Q1.D, U3.VCC(20), U4.VCC(20), R_PE.a, C_U3a.+, C_U4a.+, C_U3b.+, C_U4b.+ | **`R-HW-020`/`044`**: off until 3V3-good |
| `GATE` | Q1.G, R_G1.b, C_G.a, Q2.D | Q1 high-side gate node |
| `PG_3V3` | U6.RESET, Q2.G, R_G2.a | **`R-HW-020`**: 3V3-good drives Q2; `R_G2` fail-safe |
| `GND` | U1.GND(×n)+VREG_PGND, U2.AGND(×n), U3.GND(10), U4.GND(10), U5.GND, U6.GND, Q2.S, M1.GND, RSET.b, R_TE.b, R_G2.b, C_G.b, all C.−, J1.18–24, J2 shield/GND, J3.GND/shield, TP_GND | single local ground (design-spec.md §31) |

### 5.2 Control nets (pin-precise)

| Net | Members | Safety |
|---|---|---|
| `TE` | U1.GPIO26, U3.TE(1), U4.TE(1), R_TE.a, TP_TE | **`R-HW-040`** TE=L |
| `DC` | U1.GPIO27, U4.DC(11), R_DC.b, TP_DC | **`R-HW-040`** DC=H |
| `PE` | U3.PE(11), R_PE.b | §29 3-state select |

### 5.3 GPIB data path (U3 SN75160B) — pin-precise, `R-HW-060`

DIO1..DIO8 = GPIO0..GPIO7 (contiguous, DIO1 lowest). U3 pins: TE=1, B1..B8=2..9
(bus), GND=10, PE=11, D8..D1=12..19 (terminal), VCC=20.

| Terminal net | Members | Bus net | Members |
|---|---|---|---|
| DIO1_T | U1.GPIO0, U3.19 | DIO1_B | U3.2, J1.1 |
| DIO2_T | U1.GPIO1, U3.18 | DIO2_B | U3.3, J1.2 |
| DIO3_T | U1.GPIO2, U3.17 | DIO3_B | U3.4, J1.3 |
| DIO4_T | U1.GPIO3, U3.16 | DIO4_B | U3.5, J1.4 |
| DIO5_T | U1.GPIO4, U3.15 | DIO5_B | U3.6, J1.13 |
| DIO6_T | U1.GPIO5, U3.14 | DIO6_B | U3.7, J1.14 |
| DIO7_T | U1.GPIO6, U3.13 | DIO7_B | U3.8, J1.15 |
| DIO8_T | U1.GPIO7, U3.12 | DIO8_B | U3.9, J1.16 |

### 5.4 GPIB management path (U4 SN75161B) — pin-precise, `R-HW-061`

EOI,DAV,NDAC,NRFD = GPIO12–15 (consecutive, one PIO SM). ATN,SRQ,REN,IFC =
GPIO8–11 (Go-driven). U4 pins: TE=1, bus 2–9 (REN2 IFC3 NDAC4 NRFD5 DAV6 EOI7 ATN8
SRQ9), GND=10, DC=11, terminal 12–19 (SRQ12 ATN13 EOI14 DAV15 NRFD16 NDAC17 IFC18
REN19), VCC=20.

| Terminal net | Members | Bus net | Members | Safety |
|---|---|---|---|---|
| ATN_T | U1.GPIO8, U4.13, R_ATN.b | ATN_B | U4.8, J1.11 | `R-HW-041` |
| SRQ_T | U1.GPIO9, U4.12, R_SRQ.b | SRQ_B | U4.9, J1.10 | `R-HW-040` |
| REN_T | U1.GPIO10, U4.19, R_REN.b | REN_B | U4.2, J1.17 | `R-HW-041` |
| IFC_T | U1.GPIO11, U4.18, R_IFC.b | IFC_B | U4.3, J1.9 | `R-HW-041` |
| EOI_T | U1.GPIO12, U4.14 | EOI_B | U4.7, J1.5 | |
| DAV_T | U1.GPIO13, U4.15 | DAV_B | U4.6, J1.6 | |
| NDAC_T | U1.GPIO14, U4.17 | NDAC_B | U4.4, J1.8 | |
| NRFD_T | U1.GPIO15, U4.16 | NRFD_B | U4.5, J1.7 | |

IEEE-488 J1 (Amphenol-57 numbering): 1-4 DIO1-4, 5 EOI, 6 DAV, 7 NRFD, 8 NDAC,
9 IFC, 10 SRQ, 11 ATN, 12 shield, 13-16 DIO5-8, 17 REN, 18-23 twisted-pair returns
(→GND), 24 signal ground (→GND).

### 5.5 MCU support block (U1 RP2354A) — build from RP2350-minimal

Enter per RP "Hardware design with RP2350" / RP2350A Minimal, **omitting the flash
and R10** (RP2354 internal flash). Key nets:

- **Core SMPS:** `U1.VREG_VIN`→+3V3; `U1.VREG_LX`→`L1` 3.3 µH→**`DVDD`** (the
  ≈1.1 V core rail, pins 6/23/39) with `C7` 4.7 µF on DVDD; `U1.VREG_FB`→`DVDD`
  as the sense node; `U1.VREG_PGND`→GND; `U1.VREG_AVDD`→+3V3. L1 orientation per
  RP guidance (the magnetic field couples into C7 if it is fitted the wrong way
  round — "Hardware design with RP2350" §2.5).

  **Corrected 2026-09-21.** Earlier revisions of this line read
  "`VREG_LX`→`L1`→`+3V3` (core node)", which is wrong and destructive: it would
  tie the 3.3 V rail through the inductor to the DVDD pins and feed the ≈1.1 V
  core from 3.3 V. Raspberry Pi's "Hardware design with RP2350" is explicit that
  the regulator produces "a 1.1 V output to supply the DVDD on the chip", with
  L1 and C7 as its output filter and VREG_FB monitoring that output. DVDD is its
  own net and must never be joined to +3V3.
- **Clock:** `X1` 12 MHz between `U1.XIN`/`U1.XOUT`, `C_X1a/b` 15 pF to GND.
- **Decoupling:** 100 nF (`C_MCU`) at every IOVDD/DVDD pin; bulk per minimal.
- **USB:** `U1.USB_DP`/`U1.USB_DM` → `J3` D+/D−.
- **Boot/reset:** `SW_BOOT` on `QSPI_CSn` (+`R_BOOT`); `U1.RUN`←`R_RUN` pull-up to
  +3V3 + `SW_RUN` to GND.
- **Status LED:** `LED1` + `R_LED` on a spare GPIO (e.g. GPIO25); GPIO recorded in
  the board package (`R-HW-064`).
- **SPI to W5500:** GPIO16 MISO, GPIO17 CSn, GPIO18 SCK, GPIO19 MOSI, GPIO20 W5500-RST,
  GPIO21 W5500-INT. Carried off-sheet as hierarchical labels `ETH_MISO`, `ETH_CSn`,
  `ETH_SCK`, `ETH_MOSI`, `ETH_RSTn`, `ETH_INTn` (per the globals-for-rails,
  hierarchical-for-signals rule).
- **SWD debug (added 2026-09-22, not in revision 2).** `U1.SWCLK` and `U1.SWDIO`
  are brought out to test pads `TP_SWCLK1`/`TP_SWDIO1`. The revision-2 net table
  was silent on debug access; a first prototype with no way to attach a probe is
  a false economy, and two pads cost nothing. The alternative — declaring both
  pins `!nc` — was rejected for that reason. Not an SWD header: this is a plug-in
  dongle and the height budget is set by the Centronics connector.
- **USB-C role:** `R_CC1`/`R_CC2` 5k1 from `J3.CC1`/`J3.CC2` to GND (upstream
  facing port / device role). Both `DP1`/`DP2` are tied to `USB_DP` and both
  `DN1`/`DN2` to `USB_DM` so the cable works either way up.

  **`VBUS` is a declared non-connection.** Both VBUS contacts carry `!nc`. The
  board is powered from PoE only; bridging VBUS to `+5V_POE` or `+3V3` would
  backfeed the PoE supply from a host, or the host from the PSE, in violation of
  design-spec §30.1. Bench-powering over USB is deliberately not supported.

**Analogue rail and magnetics, added 2026-09-22 from the WIZnet W5500-EVB-Pico2
reference (SCH-W5500-EVB-Pico2-V100, rev 1.0, 2024-08-01).** The W5500 datasheet
carries no application schematic - 27 figures, none showing the magnetics bias -
so the following is taken from WIZnet's own board, which pairs a W5500 with an
RP2350 and is therefore the same architecture as this design:

- **Separate filtered analogue rail.** `+3V3` feeds ferrite `L2` to make `3V3A`;
  every `AVDD` pin (4, 8, 11, 15, 17, 21) and the magnetics bias run from `3V3A`,
  while `VDD` (28) stays on the unfiltered rail. `PWR_FLAG` marks `3V3A` as driven.
- **Series resistors on the MDI pairs.** `R_TX1`/`R_TX2`/`R_RX1`/`R_RX2`, 3R3 each,
  between the W5500 and the connector (`R15`-`R18` in the reference).
- **Bias/termination.** `R_B1` 10R from `3V3A` to `ETH_BIAS`, decoupled by
  `C_BIAS1` 100n, with `R_T1`-`R_T4` 49R9 from that node to each MDI pin
  (`R28`, `C30`, `R19`-`R22`).
- **Pull-ups the reference does not leave to the internal ones:** `R_RSTP1` 4k7 on
  `ETH_RSTn` and `R_INTP1` 4k7 on `ETH_INTn` (`R12`, `R32`/`R33`).
- **Crystal.** Loads corrected 22p -> **18p** to match the datasheet's stated 18 pF
  load capacitance, plus `R_XF1` 1M feedback across the crystal (`R24`).
- **PHY-side centre taps.** `ETH_TCT` (J2.12, the RJ45 1&2 pair) and `ETH_RCT`
  (J2.6, the 3&6 pair) are AC-grounded through 22n, following `C28`. The taps of
  the two pairs unused at 10/100 (J2.1, J2.7) are declared open.

Deliberately **not** copied from the reference: its jack uses an *external* Bob
Smith network (`C31` 1nF/2kV on the jack's GND pin) whereas ours has it internal,
so no shield capacitor or 75 R network is fitted here.

Independently confirmed by the reference, previously only inferred: the SPI GPIO
map is identical (GPIO16 MISO, 17 CSn, 18 SCK, 19 MOSI, 20 RSTn, 21 INTn);
`EXRES1` 12k4 1% to ground; `TOCAP` 4u7; `VBG` left floating; PMODE[2:0] strapped
high; 25 MHz crystal; a status LED on GPIO25. The reference also brings SWD out on
a 3-pin header, supporting the test-pad decision recorded in 5.5.

### 5.6 Ethernet + PoE block (U2 W5500, J2, M1) — build from W5500 reference

Enter per the W5500 datasheet Figure 3 + a W5500 KiCad reference. Key nets:

- **Supplies:** all AVDD/VDD → +3V3, each with 100 nF (`C_ETH`); `U2.1V2O`→`C_1V2`
  4.7 µF; analog `C_ANA` 10 nF per datasheet; AGND → GND.
- **Bias:** `U2.EXRES1`→`RSET` 12.4 kΩ 1% → GND.
- **Clock:** `X2` 25 MHz between `U2.XI`/`U2.XO` + load caps.
- **PHY↔magnetics:** `U2.TXOP/TXON/RXIP/RXIN` → `J2` transceiver-side pairs; centre-tap
  bias/termination per W5500 reference; `ACTLED`/`DUPLED` → J2 LEDs.
- **SPI:** to U1 GPIO16–21 (§5.5).
- **PoE tap → M1:** `J2` RX centre tap (pins 1&2) and TX centre tap (pins 3&6) →
  `M1` VC1(±); `J2` spare pairs (4&5, 7&8) → `M1` VC2(±). `M1.OUT` → `+5V_POE`,
  `M1.GND` → GND. WIZPoE-P1 provides the bridge rectifiers and isolation.

### 5.7 USB-C (J3) — pin-precise where it matters

- `J3` D+/D− → U1 USB (§5.5); `R_CC1`/`R_CC2` 5.1 kΩ from CC1/CC2 → GND (device).
- **`J3.VBUS` MUST NOT connect to `+5V_POE` or any power rail** (design-spec.md §30.1);
  leave for USB-powered flashing on the bench only. Shield → chassis/GND per §31.

### 5.8 Test points (§32)

`TP_TE→TE, TP_DC→DC, TP_ATN→ATN_B, TP_DAV→DAV_B, TP_NRFD→NRFD_B, TP_NDAC→NDAC_B,
TP_SRQ→SRQ_B, TP_IFC→IFC_B, TP_5V→+5V_POE, TP_3V3→+3V3, TP_GND→GND`.

---

## 6. Explicit non-connections

| Pin / net | Status | Reason |
|---|---|---|
| U1 external QSPI flash | **omitted** | RP2354A internal flash; remove flash IC + R10 (RP HD guide §3) |
| U1 QSPI_SD0-3 / SCLK | not routed externally | internal to RP2354 flash |
| `J3.VBUS` | **NC to power rails** | no PoE↔USB backfeed (design-spec.md §30.1) |
| U1 GPIO22 | test pad only | `R-HW-065` spare |
| U1 GPIO28 (CFG) | `R_CFG` to +3V3 | defined state (`R-HW-065`) |
| U3/U4 | all 20 pins each used | 8 bus + 8 term + TE + (PE\|DC) + VCC + GND |
| J1 | all 24 pins used | 16 signal + shield(12) + 7 grounds |
| UART0 (GPIO0/1) | not a console | GPIO0/1 are DIO1/DIO2; diagnostics = USB CDC (`R-HW-063`) |

---

**Added 2026-09-22, MCU sheet.** Each of these carries a no-connect flag on the
schematic and a matching `!nc` line in `netlist-spec.nets`; the checker fails if a
pin is left floating that nobody declared open.

| Pin(s) | Reason |
|---|---|
| `U1.55`–`U1.60` (QSPI SD3/SCLK/SD0/SD2/SD1/SS) | RP2354A has 2 MB stacked internal flash; the QSPI bus is not brought out. This is the `R10`/external-flash omission of §5.5 made explicit. |
| `U1.35`, `U1.36` (GPIO23, GPIO24) | Unused. The GPIO budget in §5.2 is fully assigned without them. |
| `U1.43` (GPIO29/ADC3) | Unused; no analogue input in this design. |
| `J3.A4B9`, `J3.B4A9` (VBUS ×2) | No PoE↔USB backfeed — see §5.5. |
| `J3.B8`, `J3.A8` (SBU2, SBU1) | Sideband unused; USB 2.0 device only. |

## 7. Requirement traceability (`R-HW-010`..`R-HW-065`)

| Req | Implemented by | Verified by |
|---|---|---|
| `R-HW-010` | Silkscreen/enclosure "System Controller — no second controller" | §64 inspection |
| `R-HW-011` | Product documentation | §64 doc |
| `R-HW-012` | Firmware IFC/arbitration detect → status LED (LED1) + diagnostics | §64, firmware |
| `R-HW-020` | Q1 gate on `+5V_XCVR`, driven by U6→Q2 via `PG_3V3`; `R_G1`/`R_G2` fail-safe | §64 measurement |
| `R-HW-021` | (val) measure across PoE up/down/brown-out/USB changeover; §5.8 test points | §64 report |
| `R-HW-022` | U6 `VIT-` 3.0–3.08 V; ramp via `R_G1`·`C_G`; compatible with §41/`R-FW-110` | §64 doc |
| `R-HW-030` | External bias only (`R_TE/DC/ATN/REN/IFC/SRQ`); **E9 fixed by RP2354 A4 stepping** | §64, firmware |
| `R-HW-031` | Turnaround intervals covered by bias; E9 latch hazard removed on A4 | §64 analysis |
| `R-HW-032` | (val) record RP2354 stepping (A4) of validated + production units | §64 report |
| `R-HW-040` | `R_TE`→GND (TE=L), `R_DC`→+3V3 (DC=H), `R_SRQ`→+3V3 | §64 scope |
| `R-HW-041` | `R_ATN/R_REN/R_IFC`→+3V3 on terminal nets | §64 scope |
| `R-HW-042` | Passive bias + Q1 gating cover all five conditions | §64 scope |
| `R-HW-043` | (val) scope ATN/IFC/REN/DAV/DIO in each condition | §64 report |
| `R-HW-044` | Q1 VCC gating primary; §3.2 bias secondary | §64 |
| `R-HW-050` | Power budget §3.3 | §64 measurement |
| `R-HW-051` | `C_BULK` 47 µF + Q1 `R_G1`·`C_G` soft-start; §3.3 | §64 |
| `R-HW-052` | (val) measured figures replace estimates | §64 report |
| `R-HW-053` | (val) thermal check incl. U5 0.31 W hot spot in sealed enclosure | §64 report |
| `R-HW-060` | DIO1–8 = GPIO0–7 contiguous, DIO1 lowest (§5.3) | §64 inspection |
| `R-HW-061` | EOI,DAV,NDAC,NRFD = GPIO12–15 (§5.4) | §64 inspection |
| `R-HW-062` | (doc) GPIO0–15 map load-bearing for PIO | §64 doc |
| `R-HW-063` | GPIO0/1 = DIO1/2 → USB CDC diagnostics (§5.5, §6) | §64, §65 |
| `R-HW-064` | Status LED1 on a spare GPIO, recorded in board package (§5.5) | §64 inspection |
| `R-HW-065` | GPIO22 test pad; GPIO28 `R_CFG` defined state | §64 inspection |

All twenty-four `R-HW-0xx` are covered. Sourcing risk for U3/U4 (EOL) is
design-spec.md §67 **R24** (mitigated by a hundreds-quantity buy).

---

## 8. Netlist verification procedure

As Revision 1: KiCad 7.0.11 cannot run ERC, but exports a netlist.

1. Pull footprints/symbols by LCSC number: `easyeda2kicad --full --lcsc_id=Cxxxxx`.
2. Enter the schematic (decision subsystems from §5.1–§5.4/§5.7; MCU/ETH blocks
   from the RP2350-minimal and W5500 reference designs).
3. Export: `kicad-cli sch export netlist --format kicadsexpr -o build/adapter.net adapter.kicad_sch`.
4. Check: `scripts/netlist-check.py docs/netlist-spec.nets build/adapter.net`.

`docs/netlist-spec.nets` is the machine-readable form of the **decision/safety
subsystems** (power/gate/bias/GPIB/connector, §5.1–5.4/5.7) — the parts where a
mis-wire is a safety defect. `scripts/netlist-check.py` validates spec
self-consistency now (every listed device pin assigned once; GPIO contiguity for
`R-HW-060`/`061`; no bias net on a 5 V rail; every `R-HW-0xx` covered) and, once
`adapter.net` exists, diffs those nets against the export. The MCU and Ethernet
support blocks are validated against their reference designs rather than the
canonical net table, per §1.

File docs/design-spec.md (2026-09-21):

# Design Specification: GoTMC HiSLIP + TinyGo PoE-to-GPIB Adapter

**Status:** Draft design specification — Revision 3  
**Date:** 2026-09-21  
**Target:** GoTMC ecosystem + RP2350/TinyGo PoE-to-GPIB instrument adapter  
**Primary use case:** one Ethernet/PoE adapter per GPIB instrument, plugged directly into the instrument's IEEE-488 connector

---

## 1. Executive summary

The system consists of two related deliverables:

1. **A native Go HiSLIP implementation for GoTMC**
   - Standards-oriented HiSLIP client implementation.
   - Server/device-side implementation designed so that the protocol engine can run under TinyGo.
   - Integration with `gotmc/visa`.
   - Optional GoTMC vendor extension for an explicit read request, needed to make a generic GPIB bridge fully transparent for non-SCPI instruments.
   - Shared wire codec and state-machine code between desktop Go and TinyGo firmware.

2. **A low-cost PoE Ethernet-to-GPIB adapter**
   - WIZnet W5500-EVB-Pico2 (RP2350 + W5500).
   - WIZPoE-P1 isolated IEEE 802.3af PoE module.
   - TI SN75160B data-bus transceiver.
   - TI SN75161B management-bus transceiver.
   - 24-pin male right-angle PCB-mount IEEE-488 connector.
   - TinyGo firmware exposing HiSLIP on TCP 4880 and raw SCPI on TCP 5025.
   - Adapter is System Controller and Controller-in-Charge for one locally attached GPIB instrument.

The central architectural rule is:

> HiSLIP, raw SCPI, USB debug and any future management interface never manipulate GPIB pins directly. They submit operations to one serialized GPIB engine.

This guarantees deterministic IEEE-488 bus ownership, simplifies timeout handling, and keeps protocol code separate from timing-sensitive bus code.

A second important design rule is:

> The reusable HiSLIP server core must not depend on `net.Conn`, an operating system, reflection-heavy code, or unbounded allocation.

The device-facing server core therefore depends on small `io`-like stream interfaces plus a `Device` abstraction. The normal Go client may use `net`, while TinyGo imports only the protocol and server-core packages.

---

## Revision 2 changes

This revision makes **HiSLIP Synchronized Mode mandatory for the PoE-to-GPIB device profile**.

Normative profile rules:

- the generic `gotmc/hislip` client **MUST** support both Synchronized Mode and Overlap Mode as required for a general-purpose HiSLIP client;
- the reusable server library **MAY** support both modes;
- the PoE-to-GPIB firmware profile **MUST support Synchronized Mode**;
- the PoE-to-GPIB firmware profile **MUST NOT support Overlap Mode**;
- the bridge **MUST advertise/prefer Synchronized Mode during initialization**;
- the bridge **MUST negotiate Synchronized Mode during Device Clear** and decline an Overlap proposal;
- all GPIB request/response exchange semantics, MAV handling, interrupted-response handling and bridge-side response tracking are defined against Synchronized Mode.

This change is intentional: one physical IEEE-488 instrument is fundamentally a serialized message-based resource. Emulating overlapping command/response execution in the bridge would add buffering and ambiguity without improving compatibility with the underlying GPIB device.

Note on the cost of this decision: IVI-6.1 section 3 already states that "HiSLIP servers shall support either synchronized or overlapped mode or both", and a HiSLIP session begins in Synchronized Mode. The profile rule above is therefore conformant by construction and cheap to implement — it is the `Prefer Overlap` bit of the InitializeResponse control code held at 0, plus feature bit 0 held at 0 in the Device Clear feature negotiation. The expensive part of Synchronized Mode is not mode selection but the RMT and interrupted machinery specified in §11.3.1.

---

## Revision 3 changes

Revision 3 retains the TinyGo firmware path, adds PIO as a required firmware mechanism, and closes the gaps found in the Revision 2 design review. It adds no new product scope.

**Protocol completeness (Part I)**
- Added the complete message-type table, the vendor-specific type range, and the IVI-defined error-code tables, transcribed from IVI-6.1 (§4.1, §4.3, §21.1).
- Added the normative MessageID arithmetic that Revision 2 described only conceptually (§4.2).
- Recorded a defect in IVI-6.1 Table 4 that implementers will hit (§4.4).
- Added the RMT-expected / RMT-delivered mechanism, which is mandatory for a Synchronized Mode server and was absent from Revision 2 (§11.3.1).
- Added the two-message Interrupted transaction (§11.3.2).
- Added the normative Synchronized Mode MAV rule, which is a function of MessageID equality and not merely of buffer occupancy (§11.4.1, §16.4).
- Added the Device Clear message sequence, channel assignment and timeout guidance (§13.1).
- Defined bridge behaviour when a response is expected but the instrument produces none (§17.3).
- Specified the vendor extension wire format and its capability negotiation (§17.4).

**Concurrency and scheduling (Part I / Part III)**
- Corrected the operation priority model. HiSLIP ordering is a property of the channel a message arrives on, not of its perceived urgency; Trigger is a synchronous-channel message and MUST NOT overtake queued data (§47).
- Added a mechanism allowing asynchronous operations to preempt an in-flight GPIB transfer between bytes, so that status query and device clear remain responsive while the instrument is slow (§47.1).
- Added the TinyGo runtime constraints the firmware must be designed against: cooperative scheduling within a core, no goroutine-to-core affinity, stop-the-world GC across cores, and the resulting zero-allocation rule (§5.2, §23.1).

**PIO (Part III)**
- PIO is promoted from a deferred optimization to the required implementation of the three-wire byte handshake in firmware v1. It is the only mechanism on this platform that makes handshake timing independent of the Go scheduler and garbage collector. A direct-GPIO implementation is retained as a bring-up and diagnostic path (§40).
- The GPIO map is now constrained by PIO pin-grouping rules, and the rationale is recorded so that later revisions do not silently break PIO feasibility (§28.1).

**Network stack (Part III)**
- Rewrote the W5500 socket budget against the device's actual listen model, in which a listening socket becomes the connection and there is no BSD-style accept queue. HiSLIP requires two connections to the same port (§42).
- Added an application-level session idle timeout, because the W5500 driver does not implement socket options and therefore offers no TCP keepalive; without this, an unplugged client holds a session and its sockets indefinitely (§42.2, §49.1).
- Recorded DHCP and mDNS as firmware-owned implementation work rather than platform features (§42.3).

**Hardware (Part II)**
- Added the IOVDD precondition for 5.5 V fault tolerance, and the power-sequencing requirement that follows from it (§27.1).
- Added erratum RP2350-E9 and its consequences for pull configuration on exactly the pads this design relies on (§27.2).
- Added the required external resistors and the defined bus state for MCU reset, unprogrammed and brown-out conditions (§27.3).
- Made a numeric power budget mandatory rather than asserted (§27.4).
- Recorded that the SN75161B choice makes the adapter permanently System Controller, with the resulting labelling requirement (§26.5).
- Recorded the secondary-addressing decision and the concrete controller address (§38.1).

**Document control**
- Added conformance language and requirement identifiers (§1.1).
- Added measurable throughput and latency targets so that Milestone 8 has an exit criterion (§62).
- Corrected the hardware acceptance criterion that tested the wrong pins (§64).
- Added a threat model (§66), a firmware update path (§51.1), a risk register (§67) and a requirement traceability index (§68).

---

## Revision 4 changes (proposed, not yet adopted)

Recorded here so the specification does not silently contradict the board. These
originate from the production-hardware decisions captured in
[netlist-spec.md](netlist-spec.md) §0 and are **proposed** pending review. The
`R-HW-*` requirements, the GPIO map (§28) and the GPIB physical layer (§26.3) are
unchanged by them.

- **Production board is discrete, not the module.** §26.1 and stable-decision 11
  name the W5500-EVB-Pico2 module; it remains the *development* platform, but the
  product is built from discrete **RP2354A + W5500**. netlist-spec.md realises this.
- **RP2350 → RP2354A.** The QFN-60 RP2354A (2 MB internal flash, no external QSPI)
  on the **A4 stepping fixes erratum RP2350-E9**, relaxing the input-latch basis of
  `R-HW-030`/`R-HW-031` (external bias retained for direction control). Affects §27.2.
- **Supply-sequencing element (§27.1, `R-HW-020`).** Realised as a discrete
  P-FET/N-FET high-side gate driven by a 3.3 V-regulator-good supervisor, replacing
  the load-switch-IC + separate-supervisor reading. The requirement is unchanged;
  only the implementing part changes.
- **Sourcing/assembly.** Hand-assembled first article, passives 0805 minimum, every
  BOM line an LCSC part number (JLCPCB-ready). GPIB transceiver EOL is risk **R24**.

---

## 1.1 Conformance language and requirement identifiers

The key words **MUST**, **MUST NOT**, **SHALL**, **SHALL NOT**, **SHOULD**, **SHOULD NOT** and **MAY** are to be interpreted as described in RFC 2119.

Where earlier revisions of this document wrote "recommended", read SHOULD. Where they wrote "preferably", read MAY with a stated preference. Statements of preference are not testable and MUST NOT be cited by acceptance criteria.

Testable requirements carry an identifier:

```text
[R-<AREA>-<NNN>]

AREA = PROTO   HiSLIP wire format and codec
       SYNC    Synchronized Mode semantics
       SRV     Server and session behaviour
       DEV     Device abstraction and GPIB mapping
       FW      Firmware and platform
       HW      Hardware
       SEC     Security
       DOC     Process and deliverables
```

[R-DOC-010] Every requirement identifier MUST be defined exactly once and MUST be referenced by at least one acceptance criterion in Part V. §68 holds the index.

---

# PART I — GoTMC HiSLIP

## 2. Goals

The GoTMC HiSLIP implementation shall:

- Implement IVI-6.1 HiSLIP wire framing and session semantics.
- Work as a normal Go client on Linux, macOS and Windows.
- Fit naturally into the current GoTMC stack:

```text
GoTMC application
       |
       v
   gotmc/ivi
       |
       v
   gotmc/visa
       |
       +-- USBTMC
       +-- ASRL
       +-- TCPIP/SOCKET
       +-- TCPIP/HiSLIP
```

- Provide a server core usable by TinyGo.
- Avoid ONC/Sun RPC entirely.
- Support standard VISA resource addresses such as:

```text
TCPIP0::192.168.1.42::hislip0::INSTR
```

- Preserve non-SCPI/binary transfers.
- Support HiSLIP device clear, trigger, status byte, SRQ and remote/local semantics.
- Support HiSLIP locking in the server.
- Make payload handling streaming rather than requiring the whole message in RAM.
- Be testable without physical instruments.

## 3. Non-goals for the first production milestone

The first firmware release does not need:

- VXI-11.
- ONC RPC.
- HiSLIP secure connection/TLS/SASL.
- HiSLIP authentication.
- IPv6.
- Multiple virtual instruments behind a single adapter.
- Multiple physical GPIB instruments on one adapter.
- Parallel poll.
- Secondary (extended) GPIB addressing — see §38.1.
- Pass control — precluded by the transceiver choice, see §26.5.
- Network firmware update — see §51.1.
- HTTP configuration or LXI identification server — see §42.2.
- HS488 non-interlocked handshake — see §40. Not precluded by the PIO approach, but not claimed to be achievable either.
- Full LXI certification.

These are not architectural exclusions. The interfaces must leave room for later addition.

Overlap Mode is a different case: it is a permanent normative exclusion for this device profile (§11), not a deferred feature.

---

## 4. Standards baseline

The implementation is based on **IVI-6.1 HiSLIP 2.0**. The protocol uses two TCP connections to the same server port, conventionally TCP **4880**:

- synchronous channel: normal data, END semantics, trigger, synchronized protocol traffic;
- asynchronous channel: device clear, status, service request, locking and related out-of-band operations.

Every HiSLIP packet begins with a 16-byte big-endian header:

```text
Offset  Size  Field
0       2     "HS"
2       1     Message type
3       1     Control code
4       4     Message parameter
8       8     Payload length
16      N     Payload
```

The implementation shall parse both protocol 1.x and 2.0 negotiation.

Mode support is deliberately split between the reusable library and the GPIB bridge profile:

```text
gotmc/hislip client
    MUST support Synchronized Mode
    MUST support Overlap Mode

generic gotmc/hislip server
    MUST support Synchronized Mode
    MAY support Overlap Mode

PoE-to-GPIB server profile
    MUST support Synchronized Mode
    MUST NOT support Overlap Mode
```

The recommended rollout is:

- **Milestone A:** HiSLIP 1.0 General capability, Synchronized Mode.
- **Milestone B:** full lock behavior, robust interrupted handling, complete synchronized Device Clear behavior.
- **Milestone C:** HiSLIP 2.0 General capability and descriptors, while the GPIB device profile remains Synchronized-only.
- **Optional later:** Secure Connection capability, TLS and SASL.

The TinyGo adapter should initially advertise a highest supported version of **1.0**, even though the common codec understands the 2.0 header/message namespace. This prevents the firmware from claiming HiSLIP 2.0 behavior before the additional 2.0 transactions have been validated.

### 4.1 Message types

Transcribed from IVI-6.1 Table 4. "Capability" is `General` for messages every server must support and `SC` for messages available only when the server advertises the Secure Connection capability. The `Min` column is the minimum negotiated protocol version.

```text
 #  Message                            Channel   Cap  Min
 0  Initialize                         Sync      Gen  1.0
 1  InitializeResponse                 Sync      Gen  1.0
 2  FatalError                         Either    Gen  1.0
 3  Error                              Either    Gen  1.0
 4  AsyncLock                          Async     Gen  1.0
 5  AsyncLockResponse                  Async     Gen  1.0
 6  Data                               Sync      Gen  1.0
 7  DataEnd                            Sync      Gen  1.0
 8  DeviceClearComplete                Sync      Gen  1.0
 9  DeviceClearAcknowledge             Sync      Gen  1.0   see §4.4
10  AsyncRemoteLocalControl            Async     Gen  1.0
11  AsyncRemoteLocalResponse           Async     Gen  1.0
12  Trigger                            Sync      Gen  1.0
13  Interrupted                        Sync      Gen  1.0
14  AsyncInterrupted                   Async     Gen  1.0
15  AsyncMaximumMessageSize            Async     Gen  1.0
16  AsyncMaximumMessageSizeResponse    Async     Gen  1.0
17  AsyncInitialize                    Async     Gen  1.0
18  AsyncInitializeResponse            Async     Gen  1.0
19  AsyncDeviceClear                   Async     Gen  1.0
20  AsyncServiceRequest                Async     Gen  1.0
21  AsyncStatusQuery                   Async     Gen  1.0
22  AsyncStatusResponse                Async     Gen  1.0
23  AsyncDeviceClearAcknowledge        Async     Gen  1.0
24  AsyncLockInfo                      Async     Gen  1.0
25  AsyncLockInfoResponse              Async     Gen  1.0
26  GetDescriptors                     Either    Gen  2.0
27  GetDescriptorsResponse             Either    Gen  2.0
28  StartTLS                           Sync      SC   2.0
29  AsyncStartTLS                      Async     SC   2.0
30  AsyncStartTLSResponse              Async     SC   2.0
31  EndTLS                             Sync      SC   2.0
32  AsyncEndTLS                        Async     SC   2.0
33  AsyncEndTLSResponse                Async     SC   2.0
34  GetSaslMechanismList               Sync      SC   2.0
35  GetSaslMechanismListResponse       Sync      SC   2.0
36  AuthenticationStart                Sync      SC   2.0
37  AuthenticationExchange             Sync      SC   2.0
38  AuthenticationResult               Sync      SC   2.0

39-127    reserved for HiSLIP extensions
128-255   VendorSpecific, either channel
```

The message name in IVI-6.1 is `DataEnd`. Earlier revisions of this document wrote `DataEND`; the two refer to message type 7.

[R-PROTO-010] The codec MUST reject an unknown or reserved message type with a non-fatal `Error`, code 1, and MUST NOT close the session.

[R-PROTO-011] The codec MUST reject a message that arrives on a channel other than the one listed above. Messages marked `Either` are legal on both.

[R-PROTO-012] The server MUST reject a message whose minimum version exceeds the negotiated protocol version.

[R-PROTO-013] Vendor-specific messages MUST use a type in 128–255. The GoTMC extension MUST NOT be emitted before capability negotiation succeeds (§17.4).

The firmware profile implements types 0–25 only. Types 26–38 are out of scope for the first production milestone (§3) but MUST be rejected per R-PROTO-012 rather than silently ignored.

### 4.2 MessageID arithmetic

Revision 2 described MessageID correlation conceptually. The following values are normative and are a common source of interoperability failure.

```text
initial value                  0xffffff00
increment                      +2, unsigned 32-bit, wrap-around permitted
set by client on               Data, DataEnd, Trigger
reset to 0xffffff00 on         Initialization, and after Device Clear
```

[R-PROTO-020] The client MUST maintain a MessageID counter initialised to `0xffffff00`, MUST place the current value in the message parameter field of every `Data`, `DataEnd` and `Trigger` message, and MUST then increment it by two in an unsigned 32-bit sense.

[R-PROTO-021] The client MUST reset the counter to `0xffffff00` on initialization and after Device Clear completes.

[R-PROTO-022] When the server sends `DataEnd` it MUST set the MessageID to that of the client message containing the end-of-message which generated the response.

[R-PROTO-023] When the server sends `Data` it MAY set the MessageID as in R-PROTO-022, but only when that end-of-message is at the end of the identified message. Otherwise the server MUST set the MessageID to `0xffffffff`.

[R-PROTO-024] In `AsyncStatusQuery` the client MUST send the MessageID of its most recent `Data`, `DataEnd` or `Trigger`. Immediately after Initialization and after Device Clear, before any such message has been sent, the client MUST use `0xfffffefe`, that is `0xffffff00 - 2`.

[R-PROTO-025] The client MUST validate the MessageID of received `Data` and `DataEnd` against its most recently sent value, and MUST discard the offending message and any buffered partial response when they do not match. `Data` carrying `0xffffffff` is exempt from this check.

R-PROTO-023 is the rule that lets the bridge chunk a large GPIB response: intermediate `Data` packets may be sent with `0xffffffff` while the terminating `DataEnd` carries the true MessageID.

### 4.3 Error codes

Fatal errors, IVI-6.1 Table 14. Sending a `FatalError` message is followed by closing both channels.

```text
0        Unidentified error
1        Poorly formed message header
2        Attempt to use connection without both channels established
3        Invalid Initialization Sequence
4        Server refused connection due to maximum number of clients exceeded
5        Secure connection failed
6-127    reserved for HiSLIP extensions
128-255  device defined
```

Non-fatal errors, IVI-6.1 Table 16. After sending `Error` the sender returns to normal processing.

```text
0        Unidentified error
1        Unrecognized Message Type
2        Unrecognized control code
3        Unrecognized Vendor Defined Message
4        Message too large
5        Authentication failed
6-127    reserved for HiSLIP extensions
128-255  device defined
```

The payload of both messages is a human-readable ASCII description. A zero-length payload is legal.

[R-PROTO-030] The firmware MUST use the numeric codes above and MUST NOT invent codes in the reserved range 6–127. Bridge-specific conditions MUST use 128–255 and MUST be documented in §21.1.

### 4.4 Known defect in IVI-6.1 Table 4

Table 4 lists `DeviceClearAcknowledge` (type 9) as an **asynchronous** message. The Device Clear transaction description contradicts this: the client procedure in IVI-6.1 section 6.12 step 7 reads "Wait for the server to respond with DeviceClearAcknowledge on the synchronous channel", and the message summary table lists its channel as synchronous.

[R-PROTO-040] The implementation MUST treat `DeviceClearAcknowledge` as a synchronous-channel message, matching the transaction description and observed commercial behaviour, and the channel-legality check of R-PROTO-011 MUST accept it only on the synchronous channel.

[R-PROTO-041] The interoperability tests of §24.4 MUST confirm this against at least two independent third-party HiSLIP clients before Milestone 2 closes. If a client is found that sends or expects it on the asynchronous channel, this requirement is to be revisited rather than worked around silently.

**Status: satisfied.** Two independent clients read the message from the synchronous channel, each confirmed both by source inspection and by a device clear that completes against this implementation.

pyvisa-py 0.8.1, in `device_clear_complete`:

```python
send_msg(self._sync, "DeviceClearComplete", feature_bitmap, 0)
response = DeviceClearAcknowledge(self._sync)
```

PyHiSLIP, in `device_clear`:

```python
header = self._read_hislip_message(
    self.sync_channel, self.message_types['DeviceClearAcknowledge'])[0]
```

PyHiSLIP additionally annotates its message table with the channel, and gives `DeviceClearAcknowledge` as `# S, S`, server and synchronous, against `AsyncDeviceClearAcknowledge` as `# S, A`.

The conclusion is that IVI-6.1 Table 4 is wrong about this message and the transaction description in section 6.12 is right. No implementation has been found that expects it on the asynchronous channel.

While confirming the above, pyvisa-py was also observed to agree with §4.2 on every MessageID rule: the counter initialises to `0xffffff00`, increments by two masked to 32 bits, resets to `0xffffff00` after device clear, and treats `0xffffffff` as the non-correlating value. That is independent corroboration of the constants transcribed there.

---

## 5. Repository/package structure

Recommended repository:

```text
github.com/gotmc/hislip
|
+-- protocol/
|   +-- constants.go
|   +-- version.go
|   +-- header.go
|   +-- codec.go
|   +-- errors.go
|   +-- messages.go
|   +-- messageid.go
|
+-- client/
|   +-- client.go
|   +-- connect.go
|   +-- sync.go
|   +-- async.go
|   +-- lock.go
|   +-- status.go
|   +-- clear.go
|   +-- trigger.go
|   +-- remote.go
|
+-- server/
|   +-- server.go
|   +-- session.go
|   +-- device.go
|   +-- sync.go
|   +-- async.go
|   +-- locks.go
|   +-- status.go
|   +-- clear.go
|   +-- rmt.go            RMT-expected / RMT-delivered tracking, §11.3.1
|   +-- interrupted.go    Interrupted transaction, §11.3.2
|   +-- errors.go
|
+-- extension/
|   +-- gotmc/
|       +-- protocol.go
|       +-- negotiate.go
|       +-- readrequest.go
|
+-- internal/
|   +-- teststream/
|   +-- testdevice/
|   +-- vectors/          language-neutral conformance vectors, §24.1
|
+-- examples/
    +-- query/
    +-- server/
```

### 5.1 TinyGo dependency boundary

TinyGo firmware shall import:

```text
github.com/gotmc/hislip/protocol
github.com/gotmc/hislip/server
```

It shall **not** import the desktop client package.

The `protocol` and `server` packages shall stay inside a TinyGo-friendly subset:

- `context`
- `errors`
- `io`
- `sync` only where TinyGo behavior is verified
- `time`
- simple slices and fixed arrays
- no `reflect`
- no `encoding/gob`
- no dependency on OS syscalls
- no mandatory `net`
- no unsafe pointer tricks
- no large per-message allocation

The wire codec should preferably encode/decode fixed header fields explicitly rather than using reflection-based serialization.

Note on `net`: the TinyGo W5500 driver is a `netdev` implementation, so TinyGo's `net` package and `net.Conn` are in fact available on this target. The `Stream` abstraction of §7 is therefore retained for testability and for host/target symmetry, not because `net` is unavailable. Firmware MAY wrap `net.Conn`.

#### 5.1.1 Enforcing the boundary

Stating the boundary as a rule is not sufficient. The realistic failure is not that someone imports the client package deliberately; it is that `fmt.Errorf` appears in an error path eighteen months from now and the firmware build breaks, or silently grows.

[R-DOC-030] The repository MUST contain a test that walks the transitive import graph of the device-side packages and fails when it contains a package outside an allowlist. The allowlist is the TinyGo-friendly subset named above.

[R-DOC-031] The check MUST cover `protocol` and `server` and every package they import within this module, and MUST reject `fmt`, `net`, `os`, `reflect`, `encoding/gob`, `unsafe` and the `client` package by name so that the failure message is unambiguous.

[R-DOC-032] CI MUST additionally run a `tinygo build` of the device-side packages. The import-graph test catches the cause; the TinyGo build catches everything the allowlist did not anticipate.

[R-DOC-033] Adding a package to the allowlist MUST be a deliberate, reviewed change, and the justification MUST be recorded in the test file itself rather than in a commit message.

A nested Go module for the device-side packages, with its own `go.mod` and no external requires, would make the boundary structural rather than tested. That is a stronger guarantee at the cost of separate versioning and tooling friction. It is the fallback if the tested boundary proves insufficient in practice; it is not the starting point.

### 5.2 Toolchain and firmware build profile

The firmware depends on TinyGo runtime behaviour that is version-sensitive, so the toolchain is part of the design, not an environment detail.

[R-FW-010] The firmware build MUST pin an exact TinyGo version. The pinned version MUST be recorded in the firmware repository and reported by the `show config` diagnostic (§52).

[R-FW-011] The firmware MUST compile and pass its functional tests under the target default scheduler (`-scheduler=tasks`, single core, cooperative). Multi-core operation MUST remain an optimization that can be withdrawn without functional change.

[R-FW-012] When the multi-core scheduler is enabled, the build MUST use `-scheduler=cores` and a TinyGo version in which the known cores-scheduler defects are fixed. At the time of writing that means 0.42.0 or later, which contains fixes for cores-scheduler timer starvation, the leaking-GC build, the all-core GC stop, and an RP2 USB CDC transmit race.

[R-FW-013] The firmware MUST NOT assume goroutine-to-core affinity. See §23.1.

[R-FW-014] The `go` directive in `go.mod` MUST NOT exceed the Go language version supported by the pinned TinyGo release. TinyGo 0.42.0 supports Go 1.27, so a directive of `go 1.25.0` is compatible. This constraint is easy to violate accidentally, because raising the directive breaks only the firmware build while the host build continues to succeed.

Release cadence is approximately one TinyGo minor release per four months, and patch releases are rare. The project MUST therefore be able to build from a pinned upstream commit or carry a local patch, and MUST NOT plan around an unreleased fix arriving on a schedule.

Rationale for pinning rather than tracking latest: an instrument adapter has a long service life and a slow validation cycle. The cost of re-qualifying the firmware against a new toolchain exceeds the benefit of routine upgrades.

### 5.3 Repository placement within the GoTMC ecosystem

HiSLIP is delivered as a **new standalone module, `github.com/gotmc/hislip`**, a sibling of the existing transports.

The GoTMC convention is one module per transport, each carrying its own `visa.go` for resource-string parsing, with `gotmc/visa` acting as the resource manager that imports them:

```text
gotmc/visa      resource manager; requires asrl, lxi, usbtmc
gotmc/asrl      serial
gotmc/lxi       TCPIP SOCKET, raw TCP
gotmc/usbtmc    USB
gotmc/prologix  Prologix GPIB controllers
gotmc/hislip    TCPIP INSTR, HiSLIP            <- new
```

**Why not inside `gotmc/lxi`.** HiSLIP is formally an LXI Extended Function, so the name is semantically tempting, but that repository is the raw-socket transport rather than a general LXI library. Its resource parser accepts only the `SOCKET` resource class and returns a dedicated error for anything else, so admitting HiSLIP would change its published contract. It is also a two-file module, and HiSLIP with protocol, client, server and extension packages would dominate it. Finally, `gotmc/visa` depends on `gotmc/lxi`, so coupling a rapidly changing HiSLIP implementation to it would force version churn through the resource manager during Milestones 0 to 7.

**Why not inside `gotmc/visa`.** The resource manager selects drivers; it does not implement transports. Putting a protocol implementation there inverts the existing dependency direction.

**The decisive argument is the dependency graph.** The device-side packages must compile under TinyGo (§5.1). Owning the module means owning every dependency the firmware can see. A shared module invites a desktop-only import into a package the firmware compiles, which §5.1.1 exists to prevent.

[R-DOC-040] The HiSLIP implementation MUST be a standalone Go module at `github.com/gotmc/hislip`.

[R-DOC-041] `gotmc/hislip` MUST provide its own `visa.go` following the structure of the existing transports, parsing the `INSTR` resource class with a HiSLIP subaddress and the optional explicit-port form, so that `gotmc/visa` can select on resource class without any change to `gotmc/lxi`.

[R-DOC-042] Client-side mDNS discovery, if implemented, belongs in `gotmc/lxi` because it is transport-agnostic LXI discovery. The firmware's mDNS responder (§44) is separate code with different constraints and MUST NOT share an implementation with it.

[R-DOC-043] The optional capability interfaces of §19 are a change to `gotmc/ivi`, not part of this module.

[R-DOC-044] The firmware is a separate repository (§34) and is product-specific rather than a library. It MUST NOT be placed inside `gotmc/hislip`.

**Upstream dependency.** Creating a repository in the `gotmc` organisation requires the organisation owner. Until that happens, development proceeds in a local repository using the final module path `github.com/gotmc/hislip`, which requires no upstream repository to exist. This is recorded as R19 in §67.

[R-DOC-045] Local development MUST use the final module path from the outset, so that no import rewriting is needed when the upstream repository is created.

[R-DOC-046] The repository MUST follow the conventions of the existing GoTMC modules — MIT licence with the project's own copyright line, the four-line file header comment, `.golangci.yaml`, and a `Justfile` — so that an upstream contribution needs no restructuring.

---

## 6. Core wire API

Recommended header representation:

```go
type MessageType uint8

type Header struct {
    Type       MessageType
    Control    uint8
    Parameter  uint32
    Length     uint64
}

const HeaderSize = 16
```

Do not store `"HS"` in every structure instance. It is invariant.

Suggested functions:

```go
func ReadHeader(r io.Reader) (Header, error)
func WriteHeader(w io.Writer, h Header) error

func ReadPayload(r io.Reader, n uint64, dst []byte, consume func([]byte) error) error
func WriteMessage(w io.Writer, h Header, payload []byte) error
```

`ReadHeader` must:

1. read exactly 16 bytes;
2. verify `H`, `S`;
3. parse all multibyte fields in network byte order;
4. validate message type for the current protocol version;
5. validate channel legality at the session layer;
6. reject or drain oversized messages correctly.

The codec must never do:

```go
payload := make([]byte, header.Length)
```

because `Length` is 64-bit and controlled by the peer.

Payloads are streamed through a fixed scratch buffer, e.g. 512–2048 bytes on TinyGo.

---

## 7. Stream abstraction for the server

The server core should not require `net.Conn`.

```go
type Stream interface {
    Read([]byte) (int, error)
    Write([]byte) (int, error)
    Close() error
}
```

Optional capability:

```go
type DeadlineStream interface {
    Stream
    SetDeadline(time.Time) error
}
```

A host Go adapter wraps `net.Conn`.

A TinyGo adapter wraps the W5500 TCP socket implementation.

This means the same HiSLIP session state machine can be used on:

```text
net.TCPConn          on desktop/server Go
W5500 connection     on TinyGo
net.Pipe             in unit tests
memory test stream   in deterministic protocol tests
```

---

## 8. Device-facing server API

The HiSLIP server must not know that the device is GPIB.

Recommended minimum interface:

```go
type Device interface {
    Write(ctx context.Context, p []byte, end bool) error
    Read(ctx context.Context, p []byte) (n int, end bool, err error)

    Clear(ctx context.Context) error
    Trigger(ctx context.Context) error
    ReadStatusByte(ctx context.Context) (byte, error)
    RemoteLocal(ctx context.Context, mode RemoteLocalMode) error
}
```

### 8.1 Write semantics

`end=false` means that more bytes belong to the current input message.

`end=true` means end-of-message/END has been delivered by HiSLIP.

For a GPIB backend:

```text
HiSLIP Data       -> GPIB bytes, no EOI on final byte
HiSLIP DataEND    -> final GPIB byte transferred with EOI asserted
```

When DataEND contains zero payload, it still terminates the logical input message.

### 8.2 Read semantics

`Read` returns data plus an `end` flag.

The server maps:

```text
end=false -> HiSLIP Data
end=true  -> HiSLIP DataEND
```

The GPIB backend sets `end=true` when:

- EOI is observed with the final received byte; or
- a configured EOS terminator is used and accepted as message termination.

### 8.3 Optional service-request source

Recommended optional interface:

```go
type ServiceRequestSource interface {
    ServiceRequests() <-chan byte
}
```

The byte is the status byte to report in `AsyncServiceRequest`.

For TinyGo, a fixed-capacity channel of 1 is sufficient. Repeated SRQ events while one event is pending should coalesce rather than allocate unbounded queue entries.

### 8.4 Optional reset/diagnostic interfaces

```go
type DeviceResetter interface {
    InterfaceClear(ctx context.Context) error
}

type DeviceInfo interface {
    DeviceName() string
}
```

These are not required by HiSLIP but are useful for the adapter.

---

## 9. HiSLIP session model

One logical HiSLIP session contains:

```go
type Session struct {
    ID              uint16
    Version         protocol.Version
    Mode            Mode
    Sync            Stream
    Async           Stream

    LastRxMessageID uint32
    LastTxMessageID uint32

    MaxRxMessage    uint64
    MaxTxMessage    uint64

    lockState       ...
    clearState      ...
    rqsLatched      bool
    srqStatus       byte
}
```

A session becomes usable only after both TCP channels have been associated by session ID.

The server must reject normal operations before the asynchronous channel is established.

The firmware profile supports **one active HiSLIP logical session** initially. The library itself must not impose that restriction.

---

## 10. Connection initialization

Server behavior:

```text
TCP connection #1
    |
    +-- Initialize
            |
            +-- allocate SessionID
            +-- validate subaddress
            +-- negotiate version
            +-- advertise/prefer Synchronized Mode
            +-- InitializeResponse

TCP connection #2
    |
    +-- AsyncInitialize(SessionID)
            |
            +-- associate with session
            +-- AsyncInitializeResponse
            +-- session READY
```

For the PoE-to-GPIB device profile:

```go
const SupportsSynchronized = true
const SupportsOverlap = false
```

The server shall indicate Synchronized Mode preference/capability during initialization. If a client later proposes Overlap Mode as part of Device Clear negotiation, the bridge shall decline that mode and return/retain Synchronized Mode.

Default subaddress:

```text
hislip0
```

A null subaddress should also select the only/default device.

Other subaddresses shall return an initialization error.

---

## 11. Mandatory Synchronized Mode for the GPIB device profile

The PoE-to-GPIB firmware **shall operate exclusively in HiSLIP Synchronized Mode**.

This is a normative compatibility requirement, not merely an implementation shortcut.

A physical IEEE-488 instrument is a serialized message-based endpoint:

```text
program message N
      |
      v
GPIB write
      |
      v
instrument execution
      |
      v
GPIB read / response N
      |
      v
program message N+1
```

The bridge shall preserve this ordering at the HiSLIP boundary.

### 11.1 Why Overlap Mode is not exposed

Overlap Mode would require the bridge to create concurrency that generally does not exist in the underlying GPIB instrument:

```text
HiSLIP query A ----\
HiSLIP query B -----+--> bridge-side queues/buffers --> one serialized GPIB device
HiSLIP query C ----/
```

That would require the bridge to invent command/response queueing, response ownership and buffering rules on behalf of a legacy instrument. It adds ambiguity and memory pressure without improving compatibility.

Therefore the GPIB device profile:

```text
MUST support:      Synchronized Mode
MUST NOT support:  Overlap Mode
```

The reusable host-side `gotmc/hislip` client remains a general HiSLIP client and therefore supports both modes.

### 11.2 MessageID correlation

In Synchronized Mode, the bridge shall keep a direct association between the completed client program message and any response generated from it.

Conceptually:

```text
HiSLIP MessageID N
       |
       +--> GPIB WRITE
       |
       +--> optional GPIB READ
       |
       +--> HiSLIP Data/DataEND response associated with N
```

This association must survive internal chunking. A large GPIB response may be returned as multiple HiSLIP Data packets followed by one DataEND, while retaining the correct synchronized request/response ownership.

### 11.3 Interrupted query/response behavior

The state machine shall detect an attempt to begin a new synchronized program message while a previous response remains pending.

It must not silently merge, discard or reorder response data.

The state machine shall model at least:

```text
Idle
ReceivingInput
InputComplete
ResponsePending
SendingResponse
Interrupted
Clearing
Closed
```

An interrupted-response condition must transition through the HiSLIP-defined recovery behavior and remain observable as a protocol condition rather than being hidden inside the GPIB backend.

#### 11.3.1 RMT-expected and RMT-delivered

This mechanism is the substance of Synchronized Mode and was missing from Revision 2. It is mandatory for a Synchronized Mode server.

The RMT-delivered flag is carried in **control code bit 0** of client-to-server `Data`, `DataEnd`, `Trigger`, `AsyncStatusQuery`, `AsyncStartTLS` and `AsyncEndTLS` messages. The client sets it to 1 on the first such message after it has delivered a response message terminator to its application layer, and only once per terminator.

```text
bit 0 = 0   RMT was not delivered
bit 0 = 1   RMT was delivered
```

The server maintains one boolean per session.

[R-SYNC-010] The server MUST set RMT-expected true whenever it sends a `DataEnd` message, that is whenever it delivers an RMT.

[R-SYNC-011] The server MUST clear RMT-expected when it receives `AsyncStatusQuery`, `AsyncStartTLS` or `AsyncEndTLS` with RMT-delivered set true.

[R-SYNC-012] On receiving `Data`, `DataEnd` or `Trigger`, when RMT-expected and RMT-delivered are both true or both false, the server MUST clear RMT-expected.

[R-SYNC-013] On receiving `Data`, `DataEnd` or `Trigger`, when RMT-expected and RMT-delivered differ, the server MUST declare an interrupted error. This error is reported only through the server's internal error mechanism. No indication is sent to the client.

R-SYNC-013 is deliberately silent on the wire. Implementers routinely assume every interrupted condition produces an `Interrupted` message; that is true only for the case in §11.3.2.

[R-SYNC-014] The interrupted error of R-SYNC-013 MUST increment a diagnostic counter (§52) so that a misbehaving client is observable in the field without a protocol analyser.

#### 11.3.2 The Interrupted transaction

The second interrupted case arises when the server's application layer offers a response terminator while unread client input is still queued.

[R-SYNC-020] When the server application layer requests that a response message terminator be sent, the server MUST first verify that no data is in the server input queue.

[R-SYNC-021] If input is queued, the server MUST declare an interrupted error and MUST:

1. report the interrupted error through its internal error mechanism;
2. clear the response just received from the application layer, and any other messages buffered for transmission to the client;
3. send the Interrupted transaction, comprising **both** the `Interrupted` message on the synchronous channel and the `AsyncInterrupted` message on the asynchronous channel.

[R-SYNC-022] Both messages MUST be sent. Sending only one leaves a conforming client permanently stalled, because a client that sees `Interrupted` first must not send further messages until `AsyncInterrupted` arrives, and a client that sees `AsyncInterrupted` first must discard server data until `Interrupted` arrives.

[R-SYNC-023] After interrupted error processing completes, the server MUST resume normal operation without closing the session.

For the GPIB bridge, "the server application layer offers a response terminator" corresponds to the point at which the GPIB engine has completed a read with EOI or an accepted EOS. The check of R-SYNC-020 therefore happens in the server layer, after the GPIB operation completes and before the terminating `DataEnd` is emitted.

[R-SYNC-024] Response bytes already removed from the instrument MUST be discarded, not retained for a later transaction, when R-SYNC-021 applies. The bridge MUST NOT attempt to re-deliver them, because their MessageID association is void.

The transaction is two messages, both from the server, in this order:

```text
step  sender  message            channel  control  parameter
1     server  AsyncInterrupted   async    0        MessageID
2     server  Interrupted        sync     0        MessageID
```

[R-SYNC-025] Both messages MUST carry, in the message parameter field, the MessageID of the `Data`, `DataEnd` or `Trigger` message that interrupted the server's response. This is the interrupting message, not the message whose response was discarded. Revision 2 did not state that these messages carry a MessageID at all.

[R-SYNC-026] `AsyncInterrupted` SHOULD be sent before `Interrupted`, per the order of IVI-6.1 Table 30. A conforming client tolerates either order — it has defined behaviour for detecting each first — but following the table avoids exercising the less-travelled path in third-party clients.

[R-SYNC-027] The control code of both messages MUST be zero. Neither carries a status or feature value.

### 11.4 MAV semantics

MAV handling in the bridge shall be defined exclusively against Synchronized Mode.

The bridge must maintain its own logical output state because it may have already removed bytes from the physical GPIB instrument into an adapter buffer.

Therefore the externally reported MAV bit reflects:

> whether response data for the active synchronized HiSLIP transaction is available/pending at the HiSLIP server boundary,

not merely whether the legacy instrument currently asserts MAV internally.

#### 11.4.1 Normative MAV computation

MAV is bit position 4 of the status byte. Revision 2 described MAV as a function of bridge buffer occupancy. That is incomplete: in Synchronized Mode, MAV is primarily a function of MessageID equality.

[R-SYNC-030] On receiving `AsyncStatusQuery`, the server MUST compare the MessageID it carries with the MessageID of the last `Data`, `DataEnd` or `Trigger` it received. If they are not equal, the server MUST report MAV false, regardless of whether response bytes are held in the bridge.

[R-SYNC-031] The server MUST set MAV false when the client indicates RMT-delivered in any RMT-delivered flag-carrying message.

[R-SYNC-032] Only when R-SYNC-030 and R-SYNC-031 do not force MAV false does the bridge's own output state determine MAV, per §16.3.

The inequality case of R-SYNC-030 means the server either has no data to deliver or is about to be interrupted by a pending synchronous message. The server is not required to detect and report that interrupted error in the status response; normal interrupted processing (§11.3.2) will report it subsequently.

[R-SYNC-033] Because MAV depends on the MessageID of the status query, MAV MUST be computed in the server layer. The `Device` interface of §8 deliberately carries no MessageID, and a GPIB backend MUST NOT be asked to compute MAV.

Consequence worth recording: the status byte returned by `viReadSTB` and the value an instrument returns to a `*STB?` query travelling through the normal data path can legitimately differ in bit 4, because the former is subject to R-SYNC-030 and the latter is not. This is inherent to bridging and MUST be documented in the product manual rather than smoothed over.

### 11.5 Device Clear mode negotiation

Device Clear is also the point at which HiSLIP peers may negotiate mode.

For the PoE-to-GPIB profile:

```text
client proposes Synchronized  -> accept
client proposes Overlap       -> decline; remain Synchronized
```

After Device Clear completes, the session remains in Synchronized Mode.

No firmware configuration option shall enable Overlap Mode on this product profile.

---

## 12. Locks

HiSLIP locking belongs in the server layer, not the GPIB driver.

Implement:

- exclusive lock;
- shared lock string;
- lock release;
- lock info;
- timeout handling.

For the single-client TinyGo profile this appears unnecessary, but standards-compatible VISA clients may still issue lock operations. Therefore the server shall implement the protocol even when only one application session is permitted.

The firmware can use a simplified lock manager internally while preserving protocol-visible behavior.

---

## 13. Device Clear

The server must implement the full HiSLIP device-clear transaction, including the asynchronous acknowledgement and synchronous completion handshake.

For the PoE-to-GPIB profile, Device Clear must also enforce the mode policy:

```text
post-clear mode = Synchronized
```

If the peer proposes Overlap Mode, the bridge declines it and continues in Synchronized Mode.

After protocol buffers are cleared, the server calls:

```go
device.Clear(ctx)
```

The GPIB backend maps that to **Selected Device Clear (SDC)** for the configured instrument, not blindly to the universal DCL command.

The adapter may expose a separate maintenance function for whole-interface DCL/IFC.

Device Clear must also:

- cancel a pending GPIB read;
- discard buffered response bytes;
- reset HiSLIP message-state tracking;
- clear pending query/read state;
- leave the TCP session usable.

### 13.1 Message sequence and feature bitmap

```text
step  sender  message                        channel  control code
1     client  AsyncDeviceClear               async    0
2     server  AsyncDeviceClearAcknowledge    async    feature preference
3     client  DeviceClearComplete            sync     feature request
4     server  DeviceClearAcknowledge         sync     feature setting   (see §4.4)
```

Server obligations, in order, on receiving `AsyncDeviceClear`:

1. complete any partially complete asynchronous transactions without waiting for timeouts;
2. send `AsyncDeviceClearAcknowledge` carrying the preferred feature bitmap;
3. finish sending any partially sent messages to the client, with normal behaviour and without waiting for timeouts;
4. abandon any buffered unsent transactions;
5. clear any well-formed messages already received on the synchronous channel;
6. accept and discard subsequent synchronous messages until `DeviceClearComplete` is found, while continuing to require well-formed messages;
7. send `DeviceClearAcknowledge` carrying the agreed feature bitmap;
8. resume normal operation.

The feature bitmap occupies the control code of the three messages that carry it:

```text
bit 0   Overlapped        false = Synchronized Mode, true = Overlap Mode
bit 1   Encryption mode   true = encryption mandatory
bit 2   Initial encryption true = secure connection must follow initialization
```

[R-SRV-010] The server MUST propose its preferred features in `AsyncDeviceClearAcknowledge` and MUST support every capability it proposes.

[R-SRV-011] The server MUST accept the value the client requests in `DeviceClearComplete` when it is capable of supporting it, and MUST return the resulting setting in `DeviceClearAcknowledge`.

[R-SRV-012] The PoE-to-GPIB profile MUST hold feature bit 0 at false in both `AsyncDeviceClearAcknowledge` and `DeviceClearAcknowledge`, irrespective of the client's request. This is the entire implementation of the Overlap Mode prohibition.

[R-SRV-013] The server MUST reset its MessageID tracking to `0xffffff00` when the transaction completes (§4.2).

[R-SRV-014] On encountering a poorly formed message at any point during device clear, the server MUST send `FatalError` with code 1 and perform fatal-error processing.

[R-SRV-015] If the peer does not respond in a timely fashion during device clear, the server MUST send `FatalError` and perform fatal-error processing. IVI-6.1 gives 40 to 120 seconds as reasonable values for this determination. The firmware MUST use a value in that range and MUST make it a named constant rather than an inline literal.

[R-SRV-016] Steps 1 to 7 MUST complete even when a GPIB operation is in progress. The device clear path therefore depends on the asynchronous preemption mechanism of §47.1.

R-SRV-016 is the requirement that makes device clear useful. A device clear that cannot interrupt a stuck instrument is the case the operator most needs it for.

---

## 14. Trigger

HiSLIP `Trigger` maps directly to GPIB **GET (Group Execute Trigger)** targeted at the configured instrument.

The GPIB backend sequence is:

```text
ATN asserted
UNL
listener address of target
GET
ATN released
```

Exact command sequencing should be encapsulated in the GPIB controller package and unit-tested against expected bus-command bytes.

---
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

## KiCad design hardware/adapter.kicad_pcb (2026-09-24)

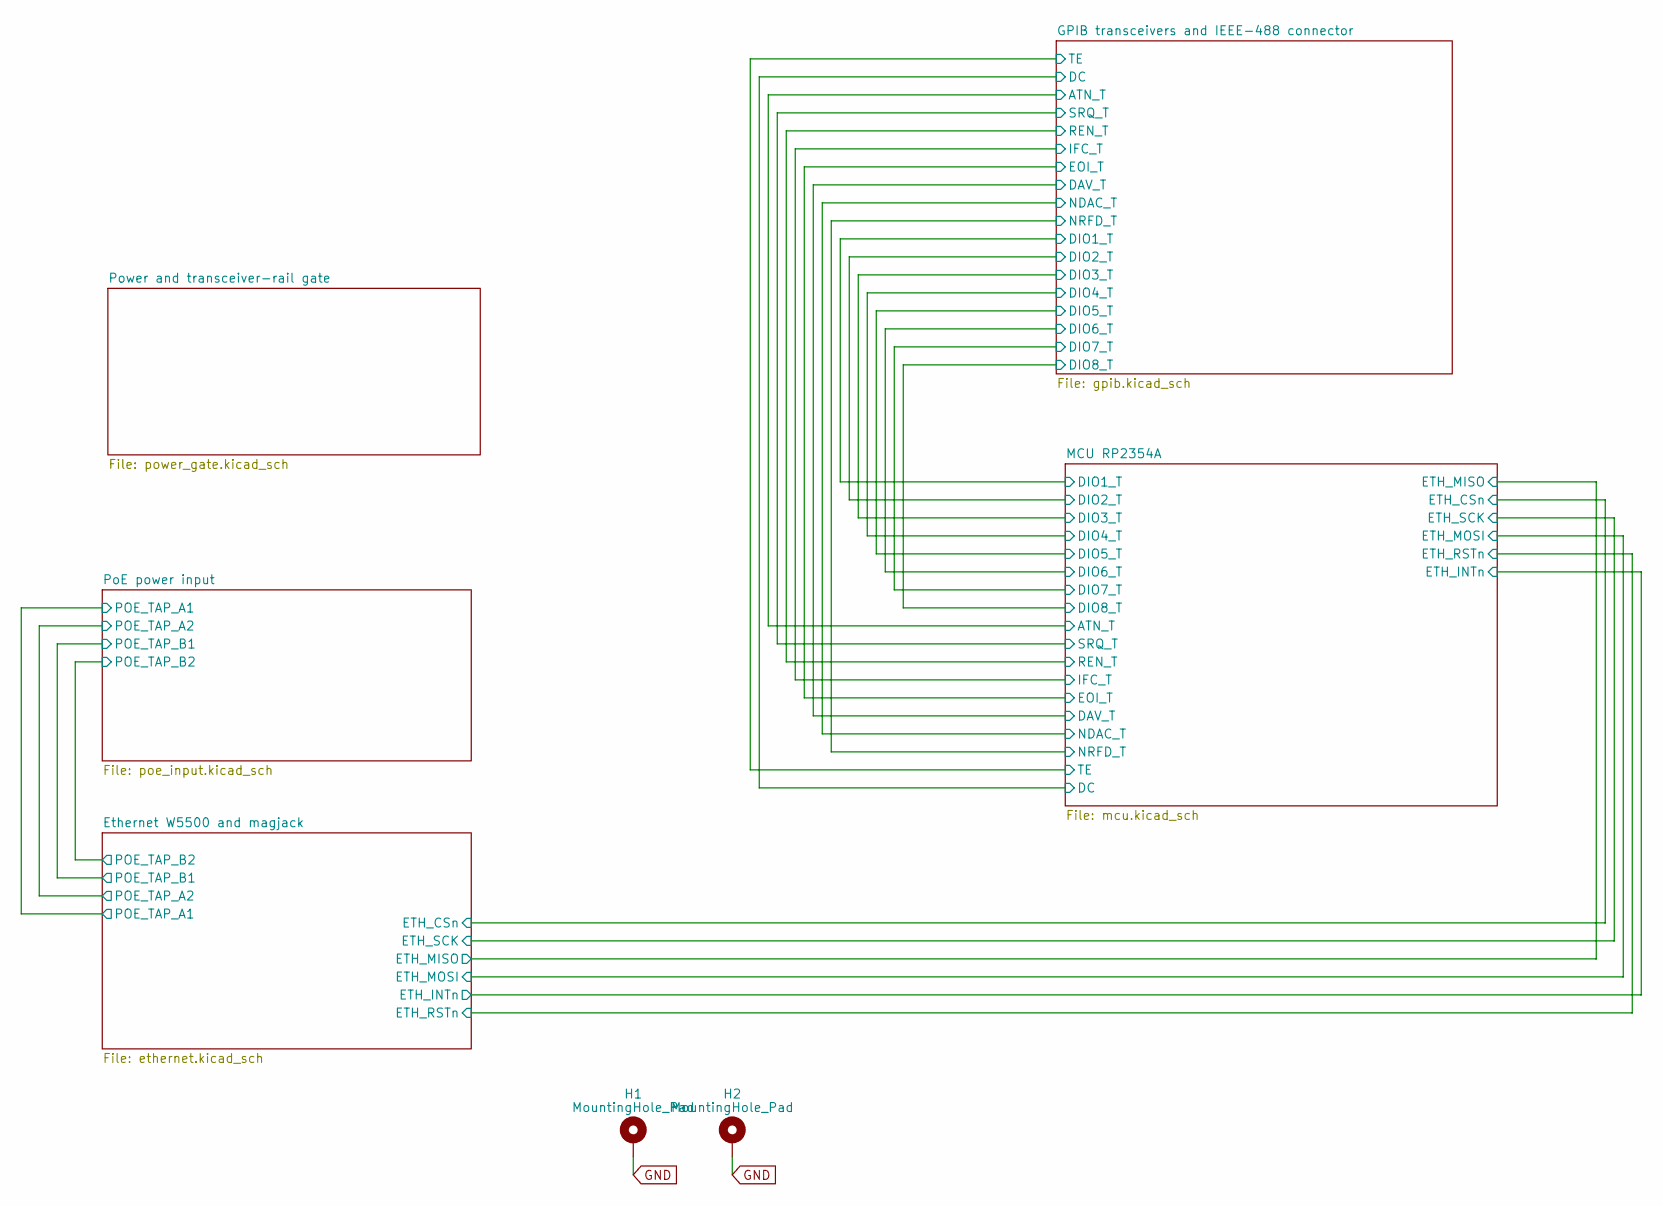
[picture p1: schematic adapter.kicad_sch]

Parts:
H1, H2: MountingHole_Pad; MountingHole_3.2mm_M3_Pad

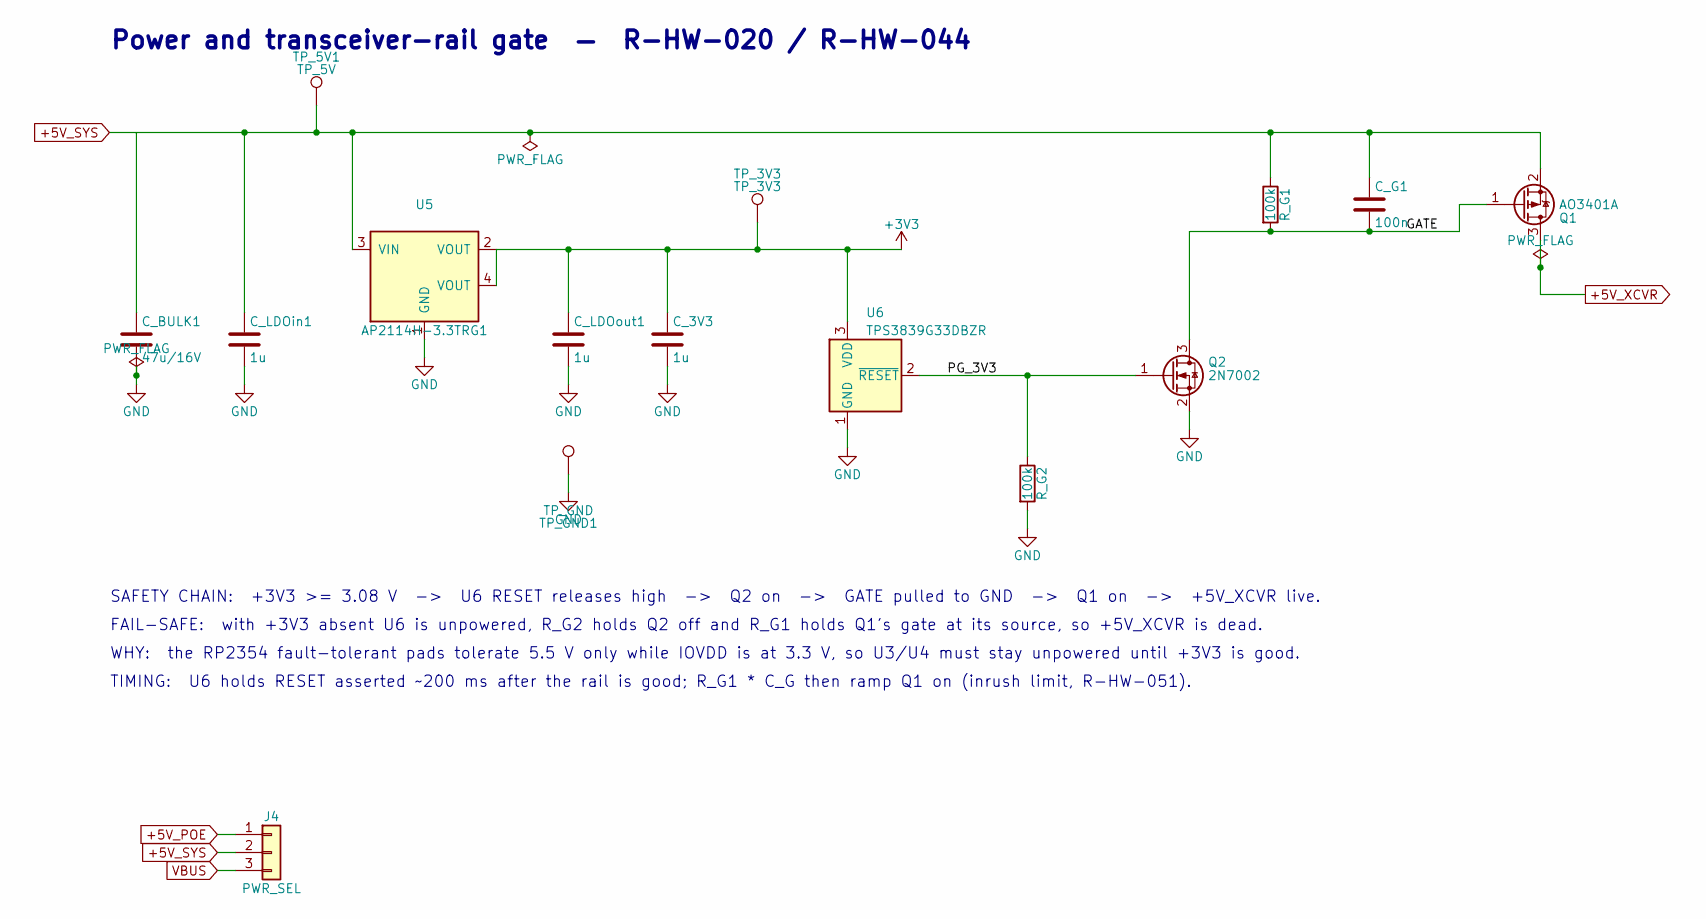
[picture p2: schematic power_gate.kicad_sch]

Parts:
C_3V3: 1u; C_0805_2012Metric
C_BULK1: 47u/16V; C_1206_3216Metric
C_G1: 100n; C_0805_2012Metric
C_LDOin1: 1u; C_0805_2012Metric
C_LDOout1: 1u; C_0805_2012Metric
J4: PWR_SEL; PinHeader_1x03_P2.54mm_Vertical
Q1: AO3401A; SOT-23
Q2: 2N7002; SOT-23
R_G1, R_G2: 100k; R_0805_2012Metric
TP_3V3: TP_3V3; TestPoint_Pad_D1.5mm
TP_5V1: TP_5V; TestPoint_Pad_D1.5mm
TP_GND1: TP_GND; TestPoint_Pad_D1.5mm
U5: AP2114H-3.3TRG1; SOT-223_L6.7-W3.5-P2.30-BR
U6: TPS3839G33DBZR; SOT-23

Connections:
+3V3: C_3V3.1, C_LDOout1.1, TP_3V3.1 (1_1), U5.2 (VOUT), U5.4 (VOUT), U6.3 (VDD); also elsewhere on the board
+5V_POE: J4.1; also elsewhere on the board
/Power and transceiver-rail gate/GATE: C_G1.2, Q1.1 (G), Q2.3 (D), R_G1.2
/Power and transceiver-rail gate/PG_3V3: Q2.1 (G), R_G2.1, U6.2 (~RESET)
VBUS: J4.3; also elsewhere on the board

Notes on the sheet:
FAIL-SAFE: with +3V3 absent U6 is unpowered, R_G2 holds Q2 off and R_G1 holds Q1's gate at its source, so +5V_XCVR is dead.
SAFETY CHAIN: +3V3 >= 3.08 V -> U6 RESET releases high -> Q2 on -> GATE pulled to GND -> Q1 on -> +5V_XCVR live.
TIMING: U6 holds RESET asserted ~200 ms after the rail is good; R_G1 * C_G then ramp Q1 on (inrush limit, R-HW-051).
WHY: the RP2354 fault-tolerant pads tolerate 5.5 V only while IOVDD is at 3.3 V, so U3/U4 must stay unpowered until +3V3 is good.
Power and transceiver-rail gate — R-HW-020 / R-HW-044

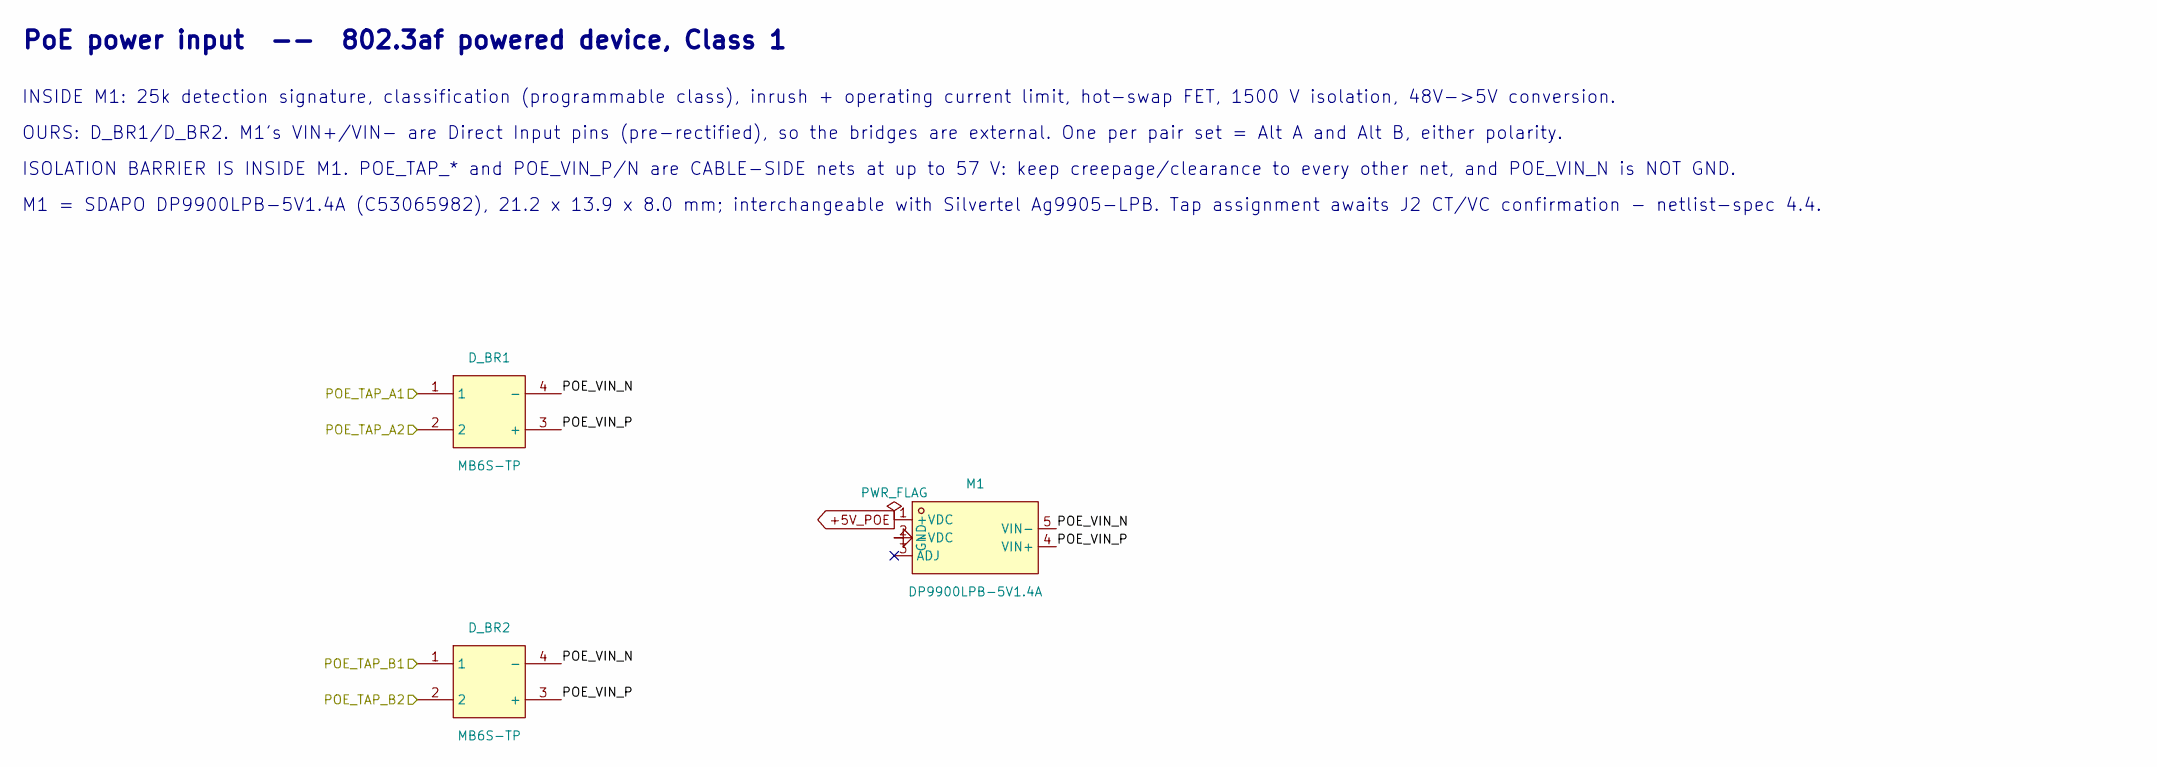
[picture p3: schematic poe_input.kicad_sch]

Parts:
D_BR1, D_BR2: MB6S-TP; MBS_L4.7-W4.0-P2.50-LS7.0-TL
M1: DP9900LPB-5V1.4A; COMM-SMD_DP9900LPB-5V1.4A

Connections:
+5V_POE: M1.1 (+VDC); also elsewhere on the board
/Ethernet W5500 and magjack/POE_TAP_A1: D_BR1.1; also elsewhere on the board
/Ethernet W5500 and magjack/POE_TAP_A2: D_BR1.2; also elsewhere on the board
/Ethernet W5500 and magjack/POE_TAP_B1: D_BR2.1; also elsewhere on the board
/Ethernet W5500 and magjack/POE_TAP_B2: D_BR2.2; also elsewhere on the board
/PoE power input/POE_VIN_N: D_BR1.4 (-), D_BR2.4 (-), M1.5 (VIN-)
/PoE power input/POE_VIN_P: D_BR1.3 (+), D_BR2.3 (+), M1.4 (VIN+)

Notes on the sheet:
OURS: D_BR1/D_BR2. M1's VIN+/VIN- are Direct Input pins (pre-rectified), so the bridges are external. One per pair set = Alt A and Alt B, either polarity.
ISOLATION BARRIER IS INSIDE M1. POE_TAP_* and POE_VIN_P/N are CABLE-SIDE nets at up to 57 V: keep creepage/clearance to every other net, and POE_VIN_N is NOT GND.
M1 = SDAPO DP9900LPB-5V1.4A (C53065982), 21.2 x 13.9 x 8.0 mm; interchangeable with Silvertel Ag9905-LPB. Tap assignment awaits J2 CT/VC confirmation - netlist-spec 4.4.
INSIDE M1: 25k detection signature, classification (programmable class), inrush + operating current limit, hot-swap FET, 1500 V isolation, 48V->5V conversion.
PoE power input -- 802.3af powered device, Class 1

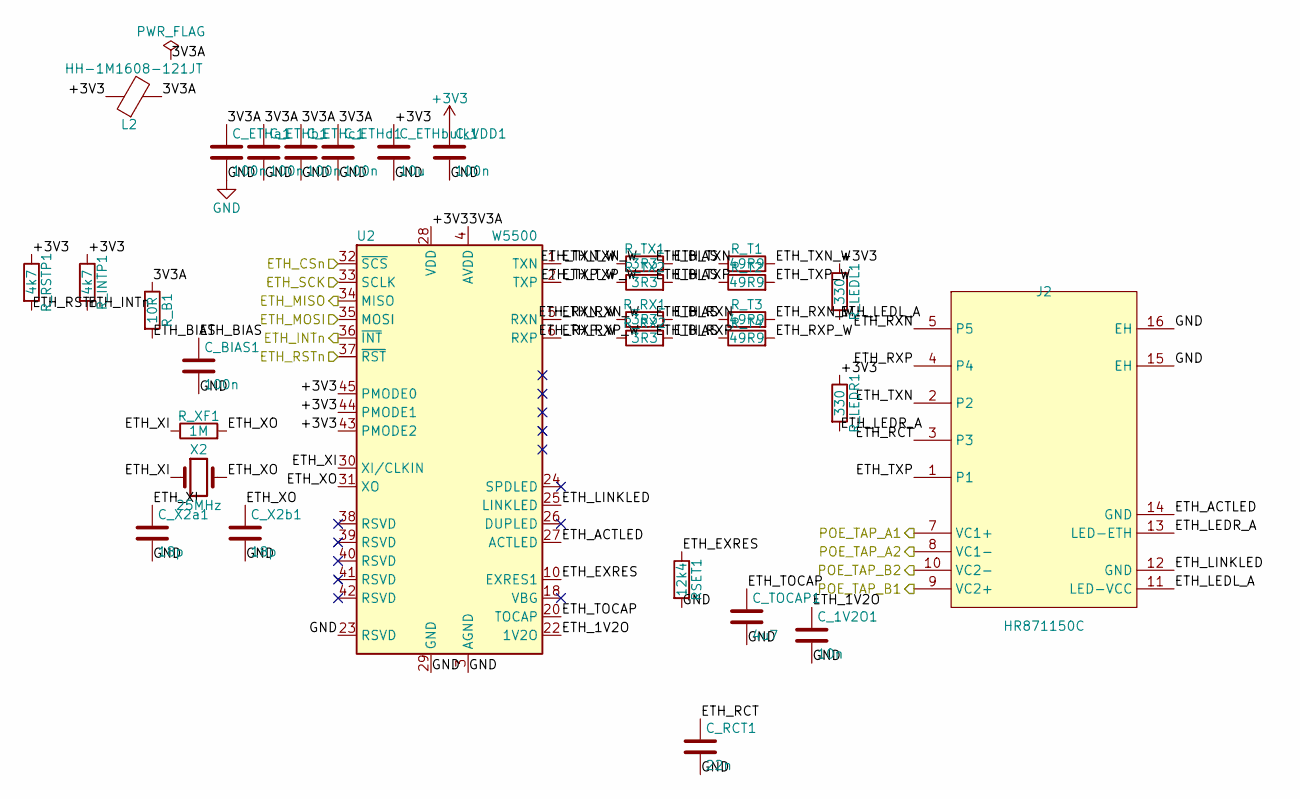
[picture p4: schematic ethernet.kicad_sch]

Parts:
C_1V2O1: 10n; C_0805_2012Metric
C_BIAS1: 100n; C_0805_2012Metric
C_ETHa1: 100n; C_0805_2012Metric
C_ETHb1: 100n; C_0805_2012Metric
C_ETHbulk1: 10u; C_0805_2012Metric
C_ETHc1: 100n; C_0805_2012Metric
C_ETHd1: 100n; C_0805_2012Metric
C_RCT1: 22n; C_0805_2012Metric
C_TOCAP1: 4u7; C_0805_2012Metric
C_VDD1: 100n; C_0805_2012Metric
C_X2a1, C_X2b1: 18p; C_0805_2012Metric
J2: HR871150C; RJ45-TH_HR871150C
L2: HH-1M1608-121JT; L_0603_1608Metric
RSET1: 12k4; R_0805_2012Metric
R_B1: 10R; R_0805_2012Metric
R_INTP1: 4k7; R_0805_2012Metric
R_LEDL1: 330; R_0805_2012Metric
R_LEDR1: 330; R_0805_2012Metric
R_RSTP1: 4k7; R_0805_2012Metric
R_RX1, R_RX2: 3R3; R_0805_2012Metric
R_T1, R_T2, R_T3, R_T4: 49R9; R_0805_2012Metric
R_TX1, R_TX2: 3R3; R_0805_2012Metric
R_XF1: 1M; R_0805_2012Metric
U2: W5500; LQFP-48_7x7mm_P0.5mm
X2: 25MHz; Crystal_SMD_3225-4Pin_3.2x2.5mm

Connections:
+3V3: C_ETHbulk1.1, C_VDD1.1, L2.1, R_INTP1.1, R_LEDL1.1, R_LEDR1.1, R_RSTP1.1, U2.28 (VDD), U2.43 (PMODE2), U2.44 (PMODE1), U2.45 (PMODE0); also elsewhere on the board
/Ethernet W5500 and magjack/3V3A: C_ETHa1.1, C_ETHb1.1, C_ETHc1.1, C_ETHd1.1, L2.2, R_B1.1, U2.4 (AVDD), U2.8 (AVDD), U2.11 (AVDD), U2.15 (AVDD), U2.17 (AVDD), U2.21 (AVDD)
/Ethernet W5500 and magjack/ETH_1V2O: C_1V2O1.1, U2.22 (1V2O)
/Ethernet W5500 and magjack/ETH_ACTLED: J2.14 (GND), U2.27 (ACTLED)
/Ethernet W5500 and magjack/ETH_BIAS: C_BIAS1.1, R_B1.2, R_T1.1, R_T2.1, R_T3.1, R_T4.1
/Ethernet W5500 and magjack/ETH_CSn: U2.32 (~SCS); also elsewhere on the board
/Ethernet W5500 and magjack/ETH_EXRES: RSET1.1, U2.10 (EXRES1)
/Ethernet W5500 and magjack/ETH_INTn: R_INTP1.2, U2.36 (~INT); also elsewhere on the board
/Ethernet W5500 and magjack/ETH_LEDL_A: J2.11 (LED-VCC), R_LEDL1.2
/Ethernet W5500 and magjack/ETH_LEDR_A: J2.13 (LED-ETH), R_LEDR1.2
/Ethernet W5500 and magjack/ETH_LINKLED: J2.12 (GND), U2.25 (LINKLED)
/Ethernet W5500 and magjack/ETH_MISO: U2.34 (MISO); also elsewhere on the board
/Ethernet W5500 and magjack/ETH_MOSI: U2.35 (MOSI); also elsewhere on the board
/Ethernet W5500 and magjack/ETH_RCT: C_RCT1.1, J2.3
/Ethernet W5500 and magjack/ETH_RSTn: R_RSTP1.2, U2.37 (~RST); also elsewhere on the board
/Ethernet W5500 and magjack/ETH_RXN: J2.5, R_RX1.2
/Ethernet W5500 and magjack/ETH_RXN_W: R_RX1.1, R_T3.2, U2.5 (RXN)
/Ethernet W5500 and magjack/ETH_RXP: J2.4, R_RX2.2
/Ethernet W5500 and magjack/ETH_RXP_W: R_RX2.1, R_T4.2, U2.6 (RXP)
/Ethernet W5500 and magjack/ETH_SCK: U2.33 (SCLK); also elsewhere on the board
/Ethernet W5500 and magjack/ETH_TOCAP: C_TOCAP1.1, U2.20 (TOCAP)
/Ethernet W5500 and magjack/ETH_TXN: J2.2, R_TX1.2
/Ethernet W5500 and magjack/ETH_TXN_W: R_T1.2, R_TX1.1, U2.1 (TXN)
/Ethernet W5500 and magjack/ETH_TXP: J2.1, R_TX2.2
/Ethernet W5500 and magjack/ETH_TXP_W: R_T2.2, R_TX2.1, U2.2 (TXP)
/Ethernet W5500 and magjack/ETH_XI: C_X2a1.1, R_XF1.1, U2.30 (XI/CLKIN), X2.1
/Ethernet W5500 and magjack/ETH_XO: C_X2b1.1, R_XF1.2, U2.31 (XO), X2.2
/Ethernet W5500 and magjack/POE_TAP_A1: J2.7 (VC1+); also elsewhere on the board
/Ethernet W5500 and magjack/POE_TAP_A2: J2.8 (VC1-); also elsewhere on the board
/Ethernet W5500 and magjack/POE_TAP_B1: J2.9 (VC2+); also elsewhere on the board
/Ethernet W5500 and magjack/POE_TAP_B2: J2.10 (VC2-); also elsewhere on the board

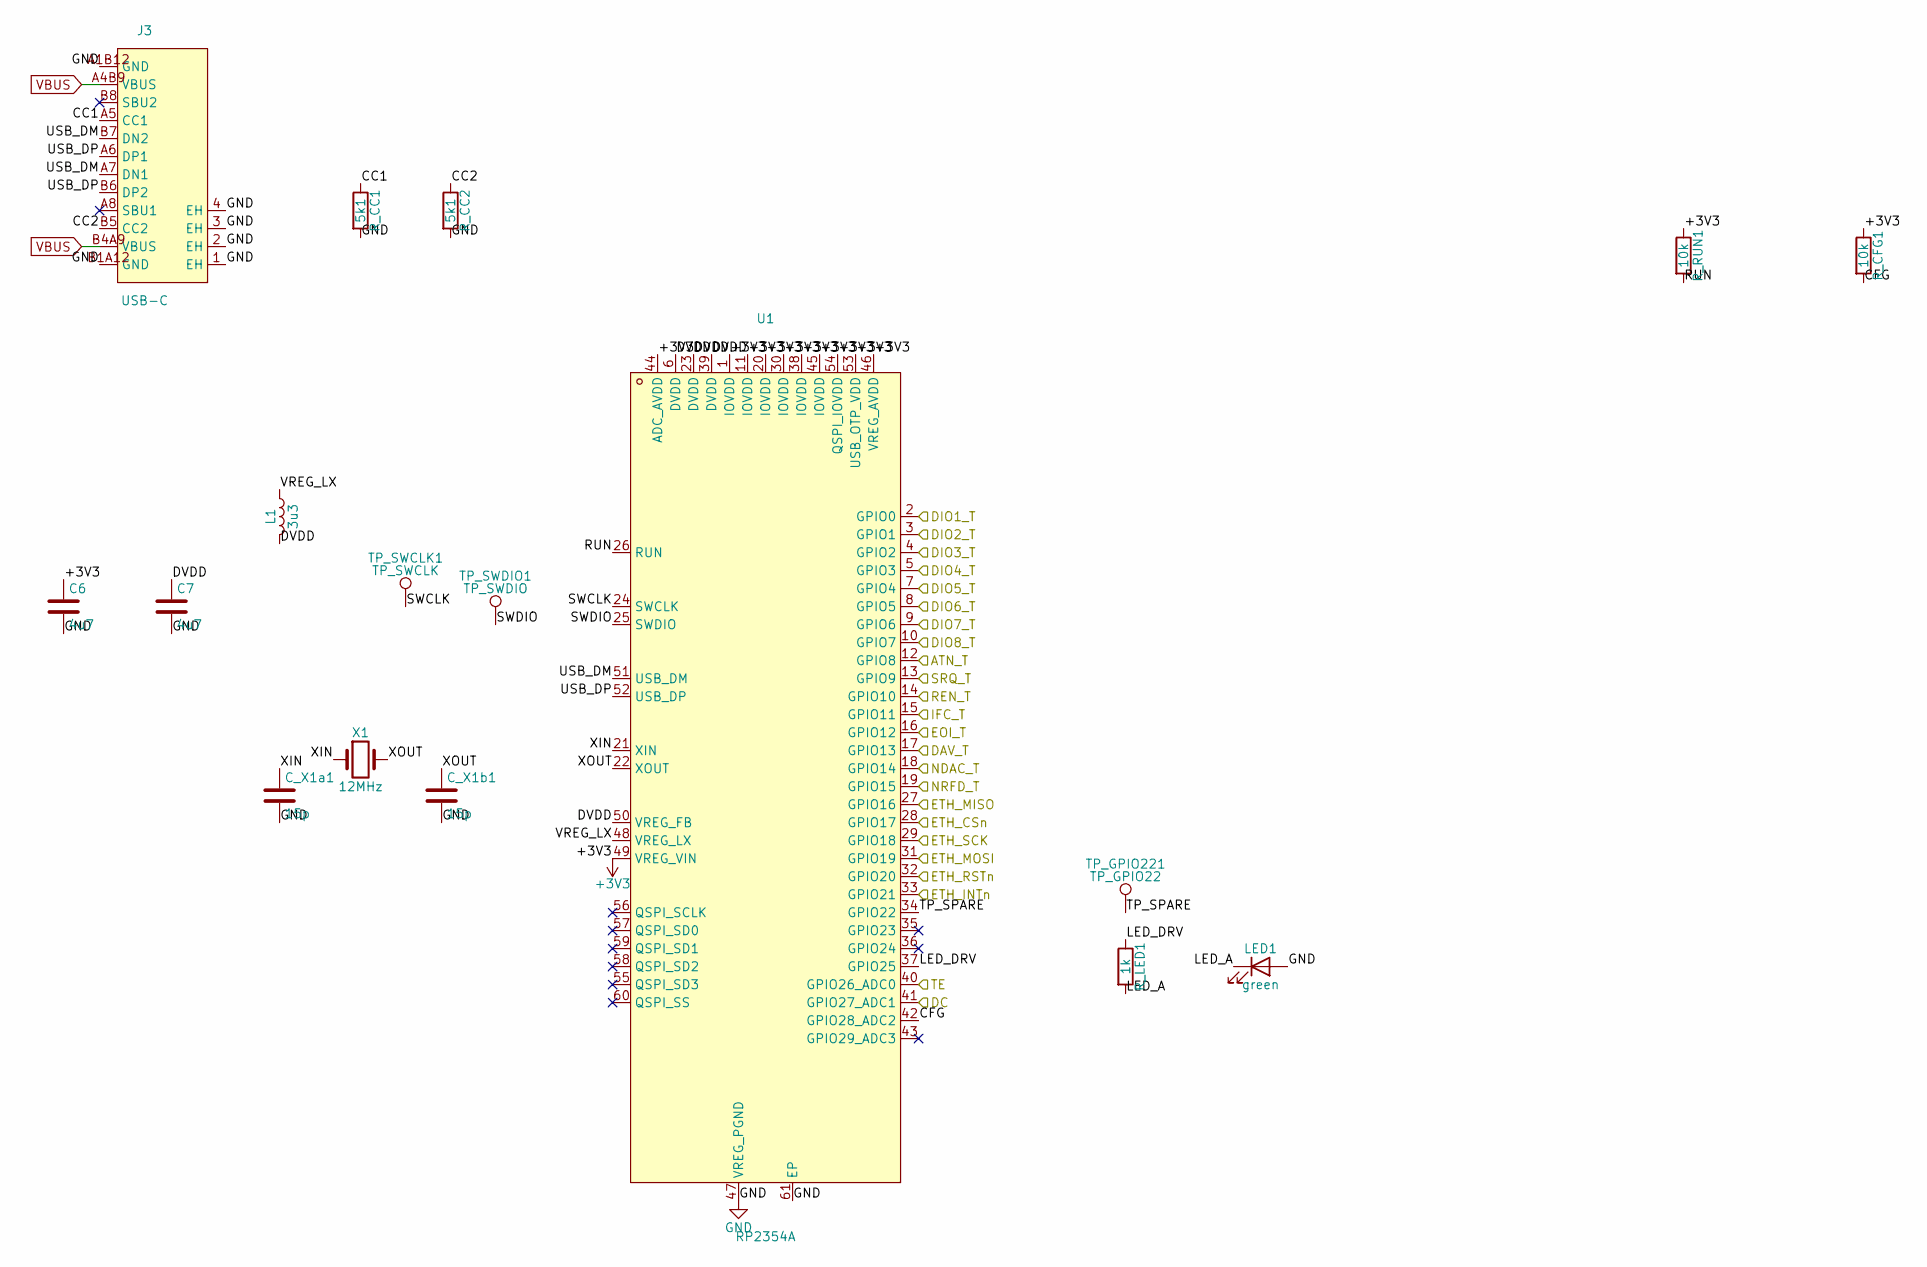
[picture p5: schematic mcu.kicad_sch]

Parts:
C6, C7: 4u7; C_0805_2012Metric
C_X1a1, C_X1b1: 15p; C_0805_2012Metric
J3: USB-C; USB-C_SMD-TYPE-C-31-M-12_1
L1: 3u3; L_0805_2012Metric
LED1: green; LED_0805_2012Metric
R_CC1, R_CC2: 5k1; R_0805_2012Metric
R_CFG1: 10k; R_0805_2012Metric
R_LED1: 1k; R_0805_2012Metric
R_RUN1: 10k; R_0805_2012Metric
TP_GPIO221: TP_GPIO22; TestPoint_Pad_D1.5mm
TP_SWCLK1: TP_SWCLK; TestPoint_Pad_D1.5mm
TP_SWDIO1: TP_SWDIO; TestPoint_Pad_D1.5mm
U1: RP2354A; QFN-60_L7.0-W7.0-P0.40-TL-EP3.4
X1: 12MHz; Crystal_SMD_3225-4Pin_3.2x2.5mm

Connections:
+3V3: C6.1, R_CFG1.1, R_RUN1.1, U1.1 (IOVDD), U1.11 (IOVDD), U1.20 (IOVDD), U1.30 (IOVDD), U1.38 (IOVDD), U1.44 (ADC_AVDD), U1.45 (IOVDD), U1.46 (VREG_AVDD), U1.49 (VREG_VIN), U1.53 (USB_OTP_VDD), U1.54 (QSPI_IOVDD); also elsewhere on the board
/Ethernet W5500 and magjack/ETH_CSn: U1.28 (GPIO17); also elsewhere on the board
/Ethernet W5500 and magjack/ETH_INTn: U1.33 (GPIO21); also elsewhere on the board
/Ethernet W5500 and magjack/ETH_MISO: U1.27 (GPIO16); also elsewhere on the board
/Ethernet W5500 and magjack/ETH_MOSI: U1.31 (GPIO19); also elsewhere on the board
/Ethernet W5500 and magjack/ETH_RSTn: U1.32 (GPIO20); also elsewhere on the board
/Ethernet W5500 and magjack/ETH_SCK: U1.29 (GPIO18); also elsewhere on the board
/GPIB transceivers and IEEE-488 connector/ATN_T: U1.12 (GPIO8); also elsewhere on the board
/GPIB transceivers and IEEE-488 connector/DAV_T: U1.17 (GPIO13); also elsewhere on the board
/GPIB transceivers and IEEE-488 connector/DC: U1.41 (GPIO27_ADC1); also elsewhere on the board
/GPIB transceivers and IEEE-488 connector/DIO1_T: U1.2 (GPIO0); also elsewhere on the board
/GPIB transceivers and IEEE-488 connector/DIO2_T: U1.3 (GPIO1); also elsewhere on the board
/GPIB transceivers and IEEE-488 connector/DIO3_T: U1.4 (GPIO2); also elsewhere on the board
/GPIB transceivers and IEEE-488 connector/DIO4_T: U1.5 (GPIO3); also elsewhere on the board
/GPIB transceivers and IEEE-488 connector/DIO5_T: U1.7 (GPIO4); also elsewhere on the board
/GPIB transceivers and IEEE-488 connector/DIO6_T: U1.8 (GPIO5); also elsewhere on the board
/GPIB transceivers and IEEE-488 connector/DIO7_T: U1.9 (GPIO6); also elsewhere on the board
/GPIB transceivers and IEEE-488 connector/DIO8_T: U1.10 (GPIO7); also elsewhere on the board
/GPIB transceivers and IEEE-488 connector/EOI_T: U1.16 (GPIO12); also elsewhere on the board
/GPIB transceivers and IEEE-488 connector/IFC_T: U1.15 (GPIO11); also elsewhere on the board
/GPIB transceivers and IEEE-488 connector/NDAC_T: U1.18 (GPIO14); also elsewhere on the board
/GPIB transceivers and IEEE-488 connector/NRFD_T: U1.19 (GPIO15); also elsewhere on the board
/GPIB transceivers and IEEE-488 connector/REN_T: U1.14 (GPIO10); also elsewhere on the board
/GPIB transceivers and IEEE-488 connector/SRQ_T: U1.13 (GPIO9); also elsewhere on the board
/GPIB transceivers and IEEE-488 connector/TE: U1.40 (GPIO26_ADC0); also elsewhere on the board
/MCU RP2354A/CC1: J3.A5 (CC1), R_CC1.1
/MCU RP2354A/CC2: J3.B5 (CC2), R_CC2.1
/MCU RP2354A/CFG: R_CFG1.2, U1.42 (GPIO28_ADC2)
/MCU RP2354A/DVDD: C7.1, L1.2, U1.6 (DVDD), U1.23 (DVDD), U1.39 (DVDD), U1.50 (VREG_FB)
/MCU RP2354A/LED_A: LED1.1 (K), R_LED1.2
/MCU RP2354A/LED_DRV: R_LED1.1, U1.37 (GPIO25)
/MCU RP2354A/RUN: R_RUN1.2, U1.26 (RUN)
/MCU RP2354A/SWCLK: TP_SWCLK1.1 (1_1), U1.24 (SWCLK)
/MCU RP2354A/SWDIO: TP_SWDIO1.1 (1_1), U1.25 (SWDIO)
/MCU RP2354A/TP_SPARE: TP_GPIO221.1 (1_1), U1.34 (GPIO22)
/MCU RP2354A/USB_DM: J3.A7 (DN1), J3.B7 (DN2), U1.51 (USB_DM)
/MCU RP2354A/USB_DP: J3.A6 (DP1), J3.B6 (DP2), U1.52 (USB_DP)
/MCU RP2354A/VREG_LX: L1.1, U1.48 (VREG_LX)
/MCU RP2354A/XIN: C_X1a1.1, U1.21 (XIN), X1.1
/MCU RP2354A/XOUT: C_X1b1.1, U1.22 (XOUT), X1.2
VBUS: J3.A4B9 (VBUS), J3.B4A9 (VBUS); also elsewhere on the board

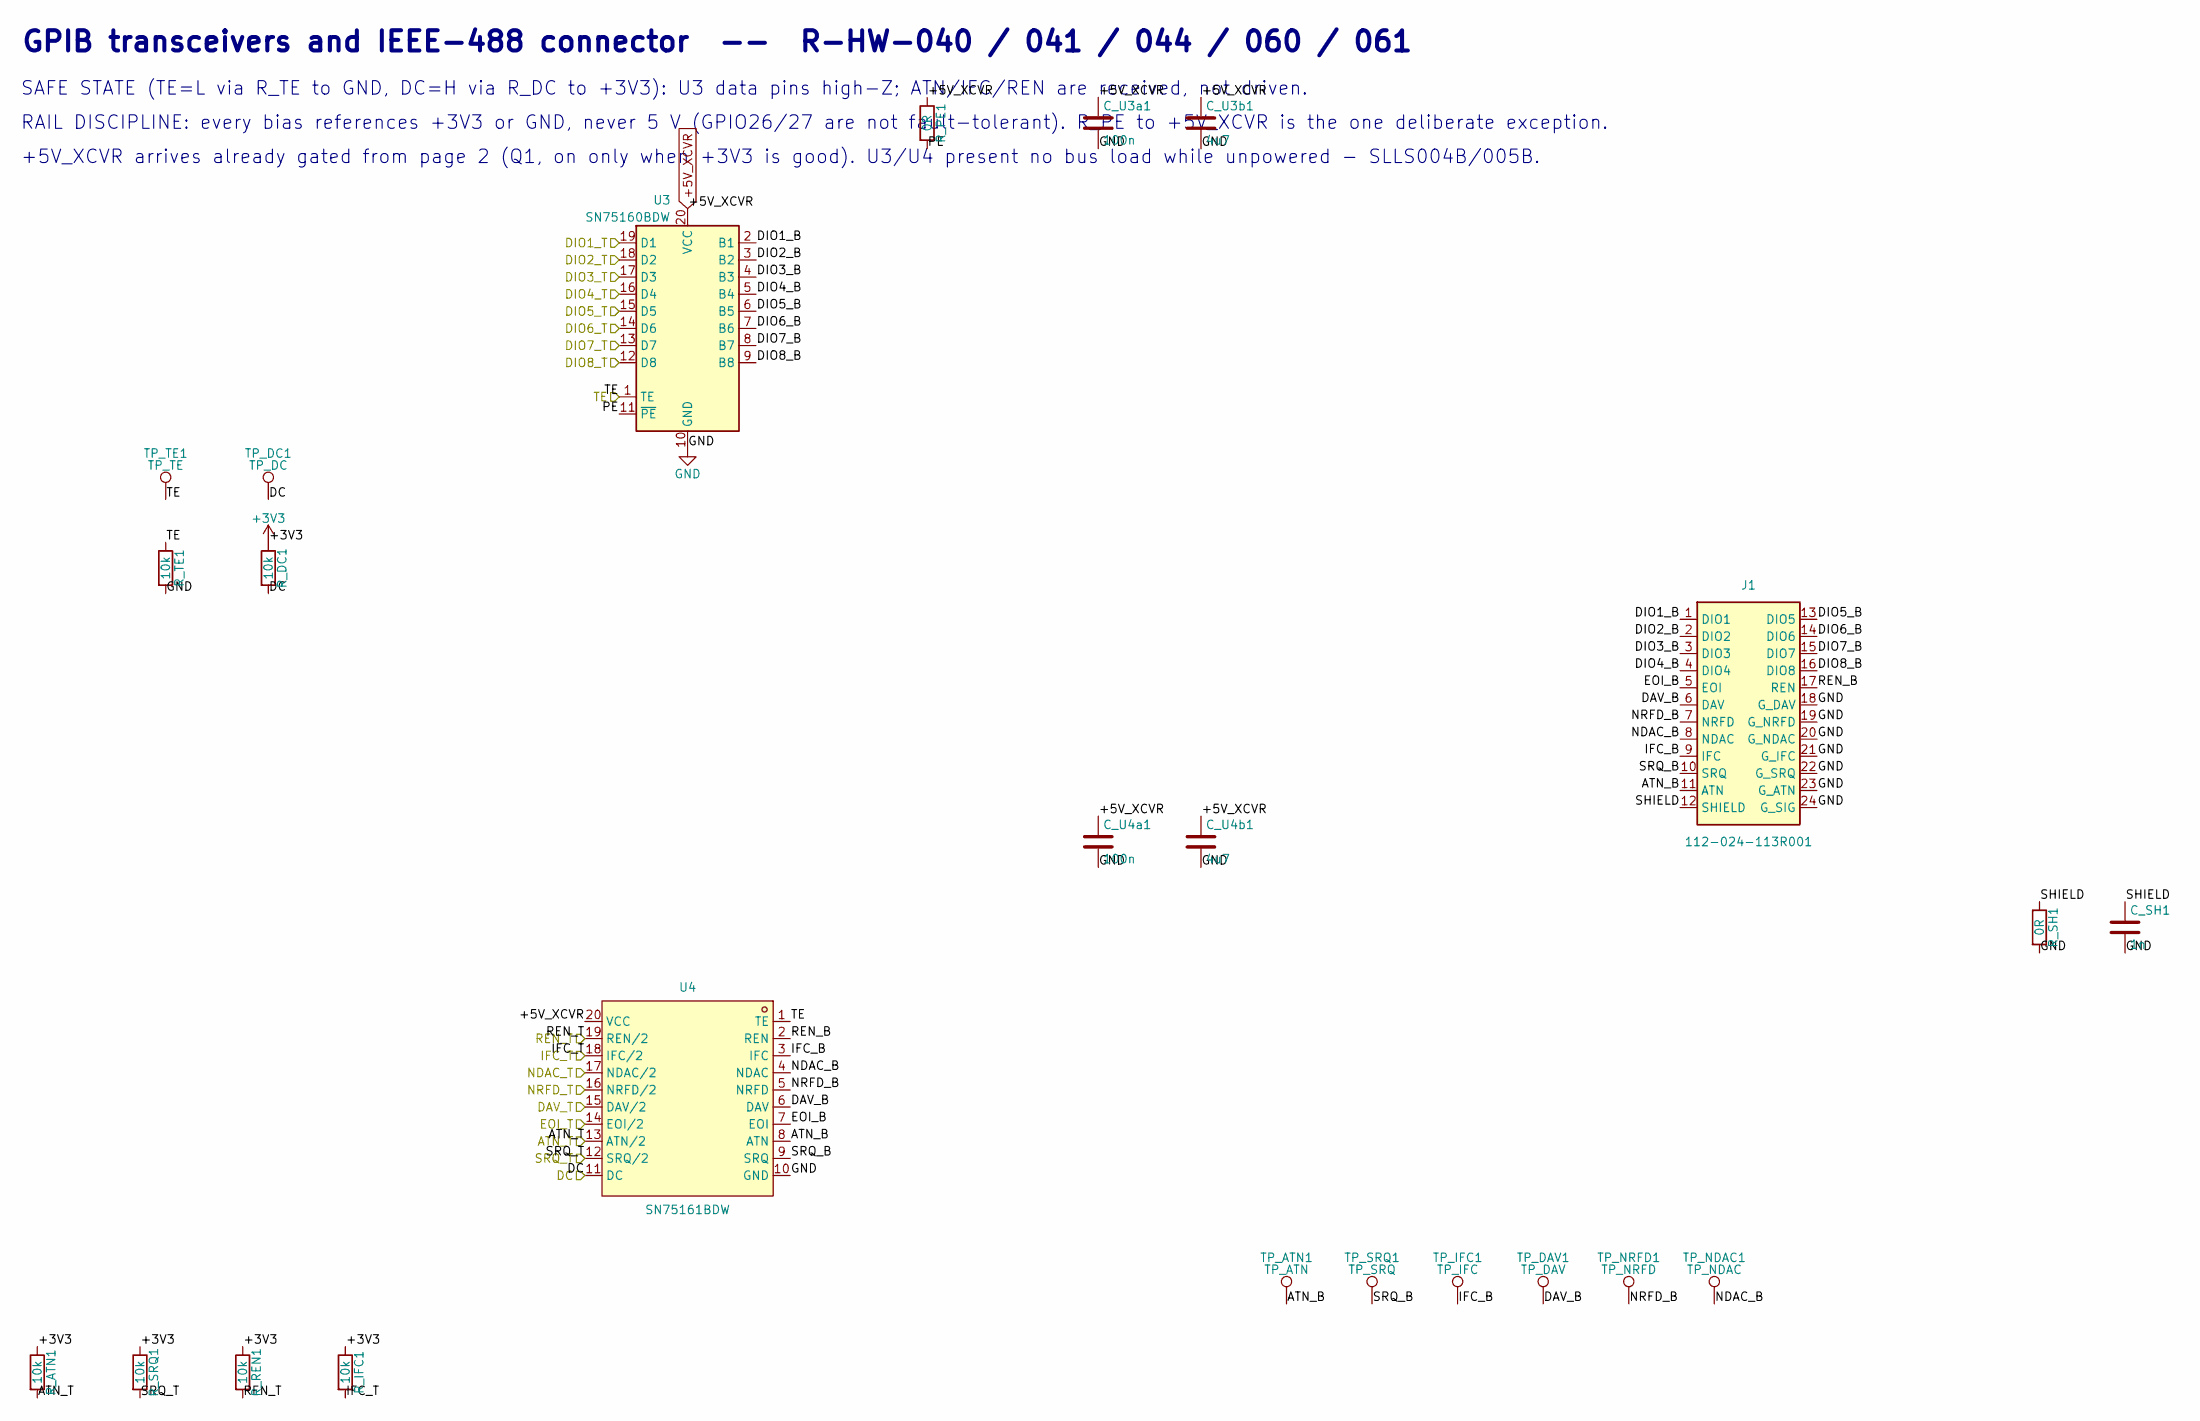
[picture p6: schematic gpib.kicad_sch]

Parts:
C_SH1: 1n; C_0805_2012Metric
C_U3a1, C_U4a1: 100n; C_0805_2012Metric
C_U3b1, C_U4b1: 4u7; C_0805_2012Metric
J1: 112-024-113R001; CONN_112-024-113R001_NRC; MPN 112-024-113R001
R_ATN1: 10k; R_0805_2012Metric
R_DC1: 10k; R_0805_2012Metric
R_IFC1: 10k; R_0805_2012Metric
R_PE1: 0R; R_0805_2012Metric
R_REN1: 10k; R_0805_2012Metric
R_SH1: 0R; R_0805_2012Metric
R_SRQ1: 10k; R_0805_2012Metric
R_TE1: 10k; R_0805_2012Metric
TP_ATN1: TP_ATN; TestPoint_Pad_D1.5mm
TP_DAV1: TP_DAV; TestPoint_Pad_D1.5mm
TP_DC1: TP_DC; TestPoint_Pad_D1.5mm
TP_IFC1: TP_IFC; TestPoint_Pad_D1.5mm
TP_NDAC1: TP_NDAC; TestPoint_Pad_D1.5mm
TP_NRFD1: TP_NRFD; TestPoint_Pad_D1.5mm
TP_SRQ1: TP_SRQ; TestPoint_Pad_D1.5mm
TP_TE1: TP_TE; TestPoint_Pad_D1.5mm
U3: SN75160BDW; SOIC-20W_7.5x12.8mm_P1.27mm
U4: SN75161BDW; SOIC-20W_7.5x12.8mm_P1.27mm

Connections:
+3V3: R_ATN1.1, R_DC1.1, R_IFC1.1, R_REN1.1, R_SRQ1.1; also elsewhere on the board
/GPIB transceivers and IEEE-488 connector/ATN_B: J1.11 (ATN), TP_ATN1.1 (1_1), U4.8 (ATN)
/GPIB transceivers and IEEE-488 connector/ATN_T: R_ATN1.2, U4.13 (ATN/2); also elsewhere on the board
/GPIB transceivers and IEEE-488 connector/DAV_B: J1.6 (DAV), TP_DAV1.1 (1_1), U4.6 (DAV)
/GPIB transceivers and IEEE-488 connector/DAV_T: U4.15 (DAV/2); also elsewhere on the board
/GPIB transceivers and IEEE-488 connector/DC: R_DC1.2, TP_DC1.1 (1_1), U4.11 (DC); also elsewhere on the board
/GPIB transceivers and IEEE-488 connector/DIO1_B: J1.1 (DIO1), U3.2 (B1)
/GPIB transceivers and IEEE-488 connector/DIO1_T: U3.19 (D1); also elsewhere on the board
/GPIB transceivers and IEEE-488 connector/DIO2_B: J1.2 (DIO2), U3.3 (B2)
/GPIB transceivers and IEEE-488 connector/DIO2_T: U3.18 (D2); also elsewhere on the board
/GPIB transceivers and IEEE-488 connector/DIO3_B: J1.3 (DIO3), U3.4 (B3)
/GPIB transceivers and IEEE-488 connector/DIO3_T: U3.17 (D3); also elsewhere on the board
/GPIB transceivers and IEEE-488 connector/DIO4_B: J1.4 (DIO4), U3.5 (B4)
/GPIB transceivers and IEEE-488 connector/DIO4_T: U3.16 (D4); also elsewhere on the board
/GPIB transceivers and IEEE-488 connector/DIO5_B: J1.13 (DIO5), U3.6 (B5)
/GPIB transceivers and IEEE-488 connector/DIO5_T: U3.15 (D5); also elsewhere on the board
/GPIB transceivers and IEEE-488 connector/DIO6_B: J1.14 (DIO6), U3.7 (B6)
/GPIB transceivers and IEEE-488 connector/DIO6_T: U3.14 (D6); also elsewhere on the board
/GPIB transceivers and IEEE-488 connector/DIO7_B: J1.15 (DIO7), U3.8 (B7)
/GPIB transceivers and IEEE-488 connector/DIO7_T: U3.13 (D7); also elsewhere on the board
/GPIB transceivers and IEEE-488 connector/DIO8_B: J1.16 (DIO8), U3.9 (B8)
/GPIB transceivers and IEEE-488 connector/DIO8_T: U3.12 (D8); also elsewhere on the board
/GPIB transceivers and IEEE-488 connector/EOI_B: J1.5 (EOI), U4.7 (EOI)
/GPIB transceivers and IEEE-488 connector/EOI_T: U4.14 (EOI/2); also elsewhere on the board
/GPIB transceivers and IEEE-488 connector/IFC_B: J1.9 (IFC), TP_IFC1.1 (1_1), U4.3 (IFC)
/GPIB transceivers and IEEE-488 connector/IFC_T: R_IFC1.2, U4.18 (IFC/2); also elsewhere on the board
/GPIB transceivers and IEEE-488 connector/NDAC_B: J1.8 (NDAC), TP_NDAC1.1 (1_1), U4.4 (NDAC)
/GPIB transceivers and IEEE-488 connector/NDAC_T: U4.17 (NDAC/2); also elsewhere on the board
/GPIB transceivers and IEEE-488 connector/NRFD_B: J1.7 (NRFD), TP_NRFD1.1 (1_1), U4.5 (NRFD)
/GPIB transceivers and IEEE-488 connector/NRFD_T: U4.16 (NRFD/2); also elsewhere on the board
/GPIB transceivers and IEEE-488 connector/PE: R_PE1.2, U3.11 (~PE)
/GPIB transceivers and IEEE-488 connector/REN_B: J1.17 (REN), U4.2 (REN)
/GPIB transceivers and IEEE-488 connector/REN_T: R_REN1.2, U4.19 (REN/2); also elsewhere on the board
/GPIB transceivers and IEEE-488 connector/SHIELD: C_SH1.1, J1.12 (SHIELD), R_SH1.1
/GPIB transceivers and IEEE-488 connector/SRQ_B: J1.10 (SRQ), TP_SRQ1.1 (1_1), U4.9 (SRQ)
/GPIB transceivers and IEEE-488 connector/SRQ_T: R_SRQ1.2, U4.12 (SRQ/2); also elsewhere on the board
/GPIB transceivers and IEEE-488 connector/TE: R_TE1.1, TP_TE1.1 (1_1), U3.1 (TE), U4.1 (TE); also elsewhere on the board

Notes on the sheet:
RAIL DISCIPLINE: every bias references +3V3 or GND, never 5 V (GPIO26/27 are not fault-tolerant). R_PE to +5V_XCVR is the one deliberate exception.
+5V_XCVR arrives already gated from page 2 (Q1, on only when +3V3 is good). U3/U4 present no bus load while unpowered - SLLS004B/005B.
SAFE STATE (TE=L via R_TE to GND, DC=H via R_DC to +3V3): U3 data pins high-Z; ATN/IFC/REN are received, not driven.
GPIB transceivers and IEEE-488 connector -- R-HW-040 / 041 / 044 / 060 / 061

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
Board: 4 copper layers, 92 parts (70 on the bottom side), 91 nets, no tracks yet.

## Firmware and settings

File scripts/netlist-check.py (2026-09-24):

#!/usr/bin/env python3
"""Check the PoE-to-GPIB adapter netlist.

Usage:
    scripts/netlist-check.py docs/netlist-spec.nets [build/adapter.net]

With one argument it validates the canonical net table for internal
consistency (this runs before any schematic exists). With a second argument
(a KiCad-exported netlist, `kicad-cli sch export netlist`) it also diffs the
exported nets against the canonical set.

See docs/netlist-spec.md section 9. No third-party dependencies.
"""

import re
import sys
from collections import defaultdict


class Spec:
    def __init__(self):
        self.pins = {}                     # ref -> pin count N (full: pins 1..N)
        self.parts = set()                 # ref of partial/reference components
        self.gpio = {}                     # signal -> gpio number
        self.reqs = []                     # required R-HW ids (order preserved)
        self.covers = set()                # R-HW ids that have a @cover line
        self.nets = {}                     # net name -> list of (ref, pin)
        self.nc = {}
        self.open_nets = {}                       # (ref, pin) -> reason


def parse_pinref(tok):
    """'R_TE.1' -> ('R_TE', '1'). Ref has no dot; pin is the tail."""
    i = tok.rfind(".")
    if i < 0:
        raise ValueError(f"pin reference without '.': {tok!r}")
    return tok[:i], tok[i + 1:]


def load_spec(path):
    s = Spec()
    with open(path, encoding="utf-8") as fh:
        for lineno, raw in enumerate(fh, 1):
            line = raw.split("#", 1)[0].strip()   # strip full-line and inline comments
            if not line:
                continue
            if line.startswith("!pins"):
                _, ref, n = line.split()
                s.pins[ref] = int(n)
            elif line.startswith("!part"):
                s.parts.add(line.split()[1])
            elif line.startswith("!gpio"):
                _, sig, num = line.split()
                s.gpio[sig] = int(num)
            elif line.startswith("!req"):
                s.reqs.append(line.split()[1])
            elif line.startswith("!open"):
                # A net that is deliberately incomplete: the missing connection
                # is an unresolved design question, not an oversight. Reported
                # as pending so the gate stays meaningful while the open item
                # stays visible.
                parts = line.split(None, 2)
                s.open_nets[parts[1]] = parts[2] if len(parts) > 2 else ""
            elif line.startswith("!nc"):
                parts = line.split(None, 2)
                ref, pin = parse_pinref(parts[1])
                s.nc[(ref, pin)] = parts[2] if len(parts) > 2 else ""
            elif line.startswith("@cover"):
                m = re.search(r"(R-HW-\d+)", line)
                if m:
                    s.covers.add(m.group(1))
            elif ":" in line:
                name, rest = line.split(":", 1)
                members = [parse_pinref(t) for t in rest.split()]
                if name in s.nets:
                    raise ValueError(f"line {lineno}: duplicate net {name}")
                s.nets[name] = members
            else:
                raise ValueError(f"line {lineno}: unparseable: {line!r}")
    return s


class Report:
    def __init__(self):
        self.checks = 0
        self.failures = []

    def ok(self, msg):
        self.checks += 1
        print(f"  PASS  {msg}")

    def fail(self, msg):
        self.checks += 1
        self.failures.append(msg)
        print(f"  FAIL  {msg}")


def check_pin_assignment(s, r):
    """Every pin of every component is assigned exactly once (net or nc),
    with no out-of-range or unknown-component references."""
    assigned = defaultdict(list)   # (ref,pin) -> list of net names ('#nc' for nc)
    for net, members in s.nets.items():
        for ref, pin in members:
            assigned[(ref, pin)].append(net)
    for (ref, pin) in s.nc:
        assigned[(ref, pin)].append("#nc")

    unknown = sorted({ref for (ref, _) in assigned
                      if ref not in s.pins and ref not in s.parts})
    if unknown:
        r.fail(f"pins reference undeclared component(s): {', '.join(unknown)}")
    else:
        r.ok(f"all pin references name a declared component "
             f"({len(s.pins)} full + {len(s.parts)} reference)")

    dups = {p: locs for p, locs in assigned.items() if len(locs) > 1}
    if dups:
        for p, locs in sorted(dups.items()):
            r.fail(f"pin {p[0]}.{p[1]} assigned {len(locs)}x: {', '.join(locs)}")
    else:
        r.ok("no pin assigned to more than one net/nc")

    # completeness: for each component, referenced pins == {1..N}
    complete = True
    for ref, n in sorted(s.pins.items()):
        got = {int(pin) for (rr, pin) in assigned if rr == ref and pin.isdigit()}
        want = set(range(1, n + 1))
        missing = sorted(want - got)
        extra = sorted(got - want)
        if missing or extra:
            complete = False
            detail = []
            if missing:
                detail.append(f"missing {missing}")
            if extra:
                detail.append(f"out-of-range {extra}")
            r.fail(f"{ref}: pins != 1..{n} ({'; '.join(detail)})")
    if complete:
        total = sum(s.pins.values())
        r.ok(f"every component pin 1..N is assigned exactly once ({total} pins total)")


def check_min_two(s, r):
    """A net with fewer than two pins is dangling."""
    bad = {n: m for n, m in s.nets.items()
           if len(m) < 2 and n not in s.open_nets}
    for n in sorted(s.open_nets):
        if n in s.nets and len(s.nets[n]) < 2:
            r.ok(f"net {n}: pending - {s.open_nets[n] or 'declared open'}")
    if bad:
        for n, m in sorted(bad.items()):
            r.fail(f"net {n} has {len(m)} pin(s); needs >= 2")
    else:
        r.ok(f"every net has >= 2 pins ({len(s.nets)} nets)")


def check_gpio_contiguity(s, r):
    """R-HW-060: DIO1..DIO8 on GPIO0..7, DIO1 lowest.
       R-HW-061: EOI,DAV,NDAC,NRFD on four consecutive GPIOs."""
    dio = [s.gpio.get(f"DIO{i}") for i in range(1, 9)]
    if None in dio:
        r.fail("R-HW-060: DIO1..DIO8 GPIO assignments incomplete")
    elif dio == list(range(dio[0], dio[0] + 8)) and dio[0] == min(dio):
        r.ok(f"R-HW-060: DIO1..DIO8 contiguous on GPIO{dio[0]}..GPIO{dio[7]}, DIO1 lowest")
    else:
        r.fail(f"R-HW-060: DIO1..DIO8 not contiguous/lowest: {dio}")

    grp = {k: s.gpio.get(k) for k in ("EOI", "DAV", "NDAC", "NRFD")}
    vals = sorted(v for v in grp.values() if v is not None)
    if len(vals) != 4:
        r.fail(f"R-HW-061: EOI/DAV/NDAC/NRFD GPIO incomplete: {grp}")
    elif len(set(vals)) == 4 and vals[-1] - vals[0] == 3:
        r.ok(f"R-HW-061: EOI,DAV,NDAC,NRFD consecutive on GPIO{vals[0]}..GPIO{vals[-1]}")
    else:
        r.fail(f"R-HW-061: EOI/DAV/NDAC/NRFD not consecutive: {grp}")


def check_bias_rail_discipline(s, r):
    """Safe-state bias must never reference a 5 V net (GPIO26/27 are non-FT;
    the FT-side pull-ups stay on +3V3 to avoid 5 V into the pad). See 3.2."""
    bias = {"R_TE", "R_DC", "R_ATN", "R_REN", "R_IFC", "R_SRQ"}
    fivev = {"+5V_POE", "+5V_SYS", "+5V_XCVR"}
    offenders = []
    for net in fivev:
        for ref, pin in s.nets.get(net, []):
            if ref in bias:
                offenders.append(f"{ref}.{pin} on {net}")
    if offenders:
        r.fail("bias resistor on a 5 V net: " + ", ".join(offenders))
    else:
        r.ok("no safe-state bias resistor (R_TE/R_DC/R_ATN/R_REN/R_IFC/R_SRQ) touches a 5 V net")


def check_requirements(s, r):
    missing = [q for q in s.reqs if q not in s.covers]
    if missing:
        r.fail("requirements with no @cover: " + ", ".join(missing))
    else:
        r.ok(f"every declared requirement has a coverage line ({len(s.reqs)} reqs: "
             f"{s.reqs[0]}..{s.reqs[-1]})")


# ---- optional: diff against a KiCad-exported netlist ----

def load_kicad_netlist(path):
    """Parser for `kicad-cli sch export netlist` (s-expr).

    Returns (nets, pinnames, refs) where
      nets     = {netname: set((ref, pin_number))}
      pinnames = {ref: {PINFUNCTION: pin_number}}
      refs     = set of every reference designator in the export

    Two normalisations matter. KiCad prefixes a sheet-local net with its sheet
    path ("Some Sheet/DIO1_B"); only the last component is the net's name. And
    KiCad identifies a pin by *number*, while this specification names the pins
    of `!part` components by function (U5.IN, Q1.S, R_G1.a) because a number
    means nothing until a symbol is chosen. `pinnames` is what lets the two be
    compared without hard-coding either.
    """
    text = open(path, encoding="utf-8").read()
    nets, pinnames, refs = {}, {}, set()
    for net_blk in re.finditer(r'\(net\b(.*?)(?=^\t\t\(net\b|\Z)', text,
                               re.S | re.M):
        blk = net_blk.group(1)
        nm = re.search(r'\(name\s+"([^"]*)"\s*\)', blk)
        if not nm:
            continue
        name = nm.group(1).strip().rsplit("/", 1)[-1]
        members = set()
        for node in re.finditer(r'\(node\b((?:\s*\([^()]*\))+)\s*\)', blk, re.S):
            nb = node.group(1)
            ref = re.search(r'\(ref\s+"([^"]*)"', nb)
            pin = re.search(r'\(pin\s+"([^"]*)"', nb)
            fn = re.search(r'\(pinfunction\s+"([^"]*)"', nb)
            if not (ref and pin):
                continue
            members.add((ref.group(1), pin.group(1)))
            refs.add(ref.group(1))
            if fn:
                pinnames.setdefault(ref.group(1), {})[fn.group(1).upper()] = \
                    pin.group(1)
        nets[name] = members
    return nets, pinnames, refs


def resolve_pin(ref, pin, pinnames):
    """Translate a specification pin id into the exported pin *number*.

    Tries, in order: it already is the number; the symbol's pin function
    (U6.RESET); the function with a 'V' prefix, since a datasheet's IN/OUT is
    a symbol's VIN/VOUT; and finally the two-terminal a/b convention.
    """
    table = pinnames.get(ref, {})
    if pin in table.values():
        return pin
    for cand in (pin.upper(), "V" + pin.upper()):
        if cand in table:
            return table[cand]
    return {"a": "1", "b": "2"}.get(pin, pin)


def diff_against_kicad(s, kpath, r):
    kicad, pinnames, exported_refs = load_kicad_netlist(kpath)
    canon = {}
    for name, members in s.nets.items():
        canon[name] = {(ref, resolve_pin(ref, pin, pinnames))
                       for ref, pin in members}
    k_by_members = {frozenset(m): n for n, m in kicad.items()}
    for name, members in sorted(canon.items()):
        key = frozenset(members)
        if key in k_by_members:
            r.ok(f"net {name}: membership matches exported net "
                 f"{k_by_members[key]!r}")
            continue
        if name in kicad:
            miss = members - kicad[name]
            extra = kicad[name] - members
            # A member whose component is not in the export at all belongs to a
            # sheet that has not been drawn yet. That is pending work, not a
            # wiring defect, and saying so keeps the real failures visible.
            if miss and not extra and all(ref not in exported_refs
                                          for ref, _ in miss):
                r.ok(f"net {name}: partial - implemented members match, "
                     f"awaiting {sorted(ref for ref, _ in miss)}")
            else:
                r.fail(f"net {name}: membership differs "
                       f"(missing {sorted(miss)}, extra {sorted(extra)})")
        else:
            if all(ref not in exported_refs for ref, _ in members):
                r.ok(f"net {name}: pending - no member component drawn yet")
            else:
                r.fail(f"net {name}: not found in exported netlist by name "
                       f"or membership")
    canon_keys = {frozenset(m) for m in canon.values()}
    for name, members in sorted(kicad.items()):
        if frozenset(members) in canon_keys or name in canon:
            continue
        if all(ref.startswith("#") for ref, _ in members):
            continue  # power-flag-only net, carries no component pin
        # KiCad invents an "unconnected-(REF-PINNAME-PadN)" net for every pin
        # left deliberately open. That is not an unspecified net: it is the
        # export's way of spelling a non-connection, so check it against the
        # specification's !nc declarations instead of reporting it as junk. A
        # pin KiCad reports as unconnected that the specification never
        # declared open is a real defect and still fails.
        if name.startswith("unconnected-") and len(members) == 1:
            ref, pin = next(iter(members))
            declared = {(r, resolve_pin(r, p, pinnames))
                        for r, p in s.nc}
            if (ref, pin) in declared:
                r.ok(f"net {name}: matches declared non-connection {ref}.{pin}")
            else:
                r.fail(f"pin {ref}.{pin} is unconnected in the export but no "
                       f"!nc declares it open")
            continue
        r.fail(f"exported net {name!r} has no counterpart in the "
               f"specification")


def main(argv):
    if len(argv) < 2:
        print(__doc__)
        return 2
    s = load_spec(argv[1])
    r = Report()

    print("Spec self-consistency:")
    check_pin_assignment(s, r)
    check_min_two(s, r)
    check_gpio_contiguity(s, r)
    check_bias_rail_discipline(s, r)
    check_requirements(s, r)

    if len(argv) >= 3:
        print(f"\nDiff against exported netlist {argv[2]}:")
        diff_against_kicad(s, argv[2], r)

    print(f"\n{r.checks} checks, {len(r.failures)} failure(s).")
    return 1 if r.failures else 0


if __name__ == "__main__":
    sys.exit(main(sys.argv))

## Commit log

2026-09-21 Initial commit: design specification and Milestone 0 protocol codec
    Adds the HiSLIP wire codec, the design specification at Revision 3, and the
    enforcement that keeps the device-side packages compilable under TinyGo.
    protocol/ implements the 16-byte header codec, the IVI-6.1 Table 4 message
    type table with channel and capability properties, the Table 14 and Table 16
    error codes, protocol version negotiation and the MessageID arithmetic.
    Two decisions shape the API:
    - The caller supplies every buffer. ReadHeader, WriteHeader, WriteMessage
    and ReadPayload take a scratch buffer rather than allocating one, so a
    device-side session can run without allocating in the data path. On the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
2026-09-21 Bump Go to 1.25, move the design spec to docs/design-spec.md
    Raises the go directive from 1.23 to 1.25.0, matching the current gotmc
    modules (asrl, prologix and visa all specify go 1.25.0), so that an upstream
    contribution needs no adjustment. Verified: the 1.25.0 toolchain resolves and
    the full suite passes under it with the race detector enabled.
    Added R-FW-014 to record the constraint that surfaced while doing this. The go
    directive must not exceed the Go language version supported by the pinned
    TinyGo release. TinyGo 0.42.0 supports Go 1.27, so 1.25.0 is safe today, but
    the failure mode is asymmetric and therefore easy to miss: raising the
    directive too far breaks only the firmware buil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
2026-09-21 Use software implementations for conformance; run the server before the client
    Records the decision to validate against software HiSLIP implementations rather
    than purchasing an instrument, and the milestone reordering that follows.
    None of the instruments on the development bench speak HiSLIP. The Siglent
    SDS3000X HD manual does not mention it once, Siglent's own application notes
    document only the raw socket on 5025 and VXI-11, and the Rigol DL3021 uses a
    raw socket on 5555. LXI compliance does not imply HiSLIP, which is an optional
    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
2026-09-21 server: Synchronized Mode machinery, Device abstraction and test doubles
    First increment of Milestone 2. Implements the state machinery that the rest of
    the server reads from, plus the abstractions and test doubles the remaining
    transactions need. The session lifecycle, dispatch, Device Clear and locks come
    next.
    RMT implements the RMT-expected and RMT-delivered mechanism of IVI-6.1 section
    3.1.1, which Revision 2 of the specification omitted entirely and which is what
    Synchronized Mode actually consists of. The two interrupted errors it can produce
    are separate values of a named type rather than one error, because they differ in
    whether the client is told: the RMT mismatch is reported only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
2026-09-21 Interoperate with pyvisa-py; fix a query misclassification it exposed
    Adds the host network adapter and an example server, then drives the result with
    pyvisa-py 0.8.1. Twelve operations pass, two are skipped because pyvisa-py does
    not implement them, none fail.
    Working against an independent client: initialization over both channels,
    queries, commands, compound messages, read_stb, the four-message device clear
    and a query after it, a 4 KiB chunked binary response, compound writes of 9.8 KB
    and 42 KB, an unanswered query that completes rather than hanging, and the
    session surviving every error path. Skipped: assert_trigger and viLock, neither
    of which pyvisa-py implements for HiSLIP, so trig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
2026-09-21 Settle R-PROTO-041 with a second client; fix two bugs libhislip found
    Three independent clients now drive the server. R-PROTO-041, the one open
    protocol question in the design, is settled.
    PyHiSLIP passes all ten transactions tried, including the three pyvisa-py cannot
    reach: device clear, trigger, and lock request, info and release. lock_info
    returned (1, 1), an exclusive lock granted to one holding client, which is the
    answer IVI-6.1 Table 23 requires. release_lock returned 1, the code for an
    exclusive release rather than the 2 of a shared one. The instrument log confirms
    the clear, the trigger and the serial poll each reached the backend exactly once.
    R-PROTO-041 asked for two independe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
2026-09-21 Extend .gitignore for KiCad, Python and local working notes
    Prepares for the hardware work and keeps two categories of file out of the
    history for different reasons.
    Generated KiCad output is ignored so that the schematic stays the single source of
    truth and a stale Gerber cannot be mistaken for the current one. Authored files are
    not: custom symbol and footprint libraries must be committed, because a schematic
    referencing a symbol nobody else has is not reproducible. The check-ignore spot
    tests confirm that split, with hardware/output/ and *.kicad_prl ignored while
    *.kicad_sym and *.kicad_sch are tracked.
    Local working notes match HANDOVER*.md and *.local.md. A session handover needs to
    b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
2026-09-21 hardware: netlist specification for the discrete PoE-to-GPIB board
    Add docs/netlist-spec.md (Revision 2): the from-scratch discrete board
    realising design-spec Part II with RP2354A + W5500. Component list with
    LCSC part numbers, a pin-precise net list for the decision/safety
    subsystems (transceiver-rail gate, GPIB safe-state bias, GPIB signal
    path, IEEE-488 connector), MCU and Ethernet as reference blocks,
    explicit non-connections, R-HW-010..065 traceability, and a power budget.
    Resolve the three open hardware decisions: supply sequencing (R-HW-020,
    a P-FET/N-FET gate on transceiver VCC driven by a 3V3-good supervisor),
    safe bus state (R-HW-040/041, TE=L / DC=H with de-assert bias reference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
    [netlist-check.py]
2026-09-22 hardware: six-sheet schematic for the PoE-to-GPIB adapter
    Authors the hierarchical schematic from docs/netlist-spec.md and gates it with
    scripts/netlist-check.py, which diffs the exported netlist against the canonical
    net table. The gate reads 131 checks / 0 failures; ERC reports 3 pin_not_driven,
    all W5500 inputs driven across a hierarchical link by bidirectional RP2350 pins.
    Sheets: root, power/transceiver gate, GPIB, PoE input, MCU, Ethernet.
    Defects this found in the Revision 2 specification, each corrected in place:
    - C166063 is an SK1117-1.5, a 1.5 V LDO, not the AP2114H-3.3 the spec recorded as
    confirmed. It would have put 1.5 V on the rail feeding IOVDD, every bias network
    and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
    [adapter.kicad_pcb, adapter.kicad_sch, ethernet.kicad_sch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]
2026-09-23 hardware: 4-layer board, placement on both sides, J1 dimensioned
    Takes the PCB from bare footprints to a fully placed 4-layer board. No
    copper is routed yet and no zones are poured.
    Stackup and outline
    Two inner copper layers added: In1.Cu intended as a solid ground plane
    directly beneath the component side, In2.Cu for power distribution. The
    board stays 62 x 68 mm. It is deliberately NOT grown: depth adds mass and
    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
    [adapter.kicad_pcb, ethernet.kicad_sch, gpib.kicad_sch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]
2026-09-24 hardware: USB-C alternate power source, J2 swapped to HanRun HR871150C
    Implements the USB-C-as-alternative-power-source design (design-spec
    §30.1): a 1x3 2.54mm header (J4) selects the system rail source via a
    jumper rather than a diode-OR, since a Schottky drop would put +5V_SYS
    below the SN75160B/161B's 4.75V minimum. Pin 1 = +5V_POE (M1's isolated
    output), pin 2 = +5V_SYS (everything downstream), pin 3 = VBUS (from
    J3's USB-C pads, already present with 5k1 CC pull-downs). R_G1/C_G1 stay
    referenced to +5V_SYS along with Q1's source (R-HW-020): the gate
    pull-up must track whichever rail the source actually sits on, or Q1
    turns on with IOVDD absent whenever the other source is unpowered.
    J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
    [adapter.kicad_pcb, adapter.kicad_sch, ethernet.kicad_sch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]
2026-09-25 gpib: define the shared Instrument abstraction; hislipfront adapts it to hislip/server.Device
    gpib.Instrument is what every host-facing protocol front end on this
    board -- HiSLIP over PoE/Ethernet, USBTMC and USBTMC-USB488 over USB --
    will drive to reach the real GPIB instrument, so none of them need their
    own bespoke bus access code. Deliberately not a copy of
    hislip/server.Device despite the same underlying intent (that package's
    own doc comment states the identical principle): RemoteEnable,
    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
2026-09-25 Add a README
    Covers what this board does (HiSLIP/USBTMC-USB488/raw-SCPI-to-GPIB
    gateway, one adapter per instrument), the hardware bill of materials,
    the gpib.Instrument/hislipfront software split and why it's shaped the
    way it is, and an honest status table -- most of the USB side and the
    actual bus driver don't exist yet.
    The 131-checks figure from an old HANDOVER note turned out to be stale:
    actually running scripts/netlist-check.py against the current committed
    schematic gives 124 checks, 0 failures. Used that instead of repeating
    the old number unverified.
2026-09-25 Add a Justfile and cmd/tinygocheck, verified against a real tinygo build
    Mirrors hislip's own cmd/tinygocheck and just tinygo recipe (see that
    repository for why tinygo build needs a real main package rather than a
    bare library import). This one wires gpib.Instrument through
    hislipfront.NewDevice and hislip/server.New, so it exercises this
    repository's actual dependency graph -- not just hislip in isolation --
    for the pico2 (RP2350) target.
    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
2026-09-25 usbtmcfront: adapt USBTMC/USB488 Bulk-OUT messages to gpib.Instrument
    The USB-side counterpart to hislipfront, unblocked by usbtmc/wire's new
    device-side codec (decode Bulk-OUT, encode DevDepMsgIn). Handler
    dispatches DevDepMsgOut to Instrument.Write, RequestDevDepMsgIn to
    Instrument.Read plus a real DevDepMsgIn response, and Trigger to
    Instrument.Trigger.
    Depends on github.com/gotmc/usbtmc via a replace directive rather than
    a plain require, since that fork deliberately keeps its original
    module path (see its own README) for an eventual upstream PR --
    depending on our fork's new wire subpackage needs the redirect.
    Scope, stated in the package doc comment: works on one already-
    reassembled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
2026-09-25 usbep + cmd/firmware: a real, tinygo-built USB skeleton for USBTMC/USB488
    usbep is the portable, unit-testable core: Reassembler turns a stream of
    small USB packets into complete USBTMC messages using each message's own
    TransferSize field (rather than packet-boundary heuristics), and
    ChunkSender splits an outgoing message back into packets no larger than
    one USB IN endpoint packet, including the trailing zero-length packet
    USB requires when a transfer's real data is an exact multiple of the max
    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
2026-10-05 cmd/firmware: fix two ISR-safety bugs found on real hardware
    Verified on a real W5500-EVB-Pico2 (RP2350): the composed USB descriptor
    enumerates exactly as designed, and a real USBTMC RequestDevDepMsgIn
    Bulk-OUT/IN round trip now produces a correctly encoded response.
    Two bugs found and fixed along the way, both specific to running inside
    TinyGo's bare-metal USB interrupt handlers:
    - main() called machine.EnableCDC a second time, overwriting the working
    handlers TinyGo's own initUSB already installed via
    machine/usb/cdc.EnableUSBCDC, which silently broke the debug console.
    - usbtmcRxHandler called println, reasm.Feed, append, and
    usbtmcfront.Handler.HandleBulkOut directly from USB i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
2026-10-05 cmd/firmware: add an interactive debug console and persistent stats
    Adds cmd/firmware/debug.go: a line-buffered command console over the
    existing CDC port (help/stats/last/clear/uptime/ping), backed by
    firmwareStats -- persistent counters for packets in, overflow/error/
    response-path events, and TX sends/failures -- plus a bounded hex dump
    of the last reassembled message and response. All reads from
    machine.USBCDC and all allocation happen only in the main loop, matching
    this file's existing ISR-safety rule (see the previous commit).
    Built ahead of the next real-hardware session (the real GPIB prototype),
    so a stuck/misbehaving device can be inspected over the serial console
    instead of need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
2026-10-05 cmd/firmware: add a version command reporting the exact build
    Justfile's firmware recipe now bakes the git commit (+ "-dirty" if the
    tree had uncommitted changes) and a UTC build timestamp into
    firmwareVersion via tinygo build -ldflags "-X main.firmwareVersion=...".
    Printed on boot and available as the "version" debug-console command.
    So that, on the next real-hardware session, it's possible to confirm
    exactly which firmware build is actually running on a given board
    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
2026-10-05 cmd/debugconsole: add an explicit port picker
    Replaces the old silent autoDetectPort with a real screen (picker.go):
    lists serial.GetPortsList(), tags entries that look like USB CDC ACM
    (usbmodem/ttyACM), rescans once a second so a board plugged in after
    launch shows up without a manual refresh, enter connects, q/esc cancels.
    -port still skips the picker entirely for scripted use.
    Addresses real user feedback after the first test: no response text
    and no way to pick a device. The missing responses turned out to be an
    unrelated device hang (confirmed by testing go.bug.st/serial directly
    against the board both hung and freshly reset -- the library's read
    path works correctly once the device i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
2026-10-14 hardware: updated board design (reference renumbering, LED polarity fix, crystal symbol upgrade)
    Replaces the schematics/PCB/project file with the latest design. Key
    changes, verified before committing (netlist-check.py: 124 checks, 0
    failures; ERC unchanged at 3 known pin_not_driven findings on W5500 SPI
    inputs, same severity-policy artifact as before):
    - Component reference designators changed from descriptive names
    (R_ATN, C_3V3, D_BR1, etc.) to plain auto-numbered ones (R15, C9, D1,
    etc.) -- intentional, since descriptive names were ending up on the
    silkscreen; they belong in the BOM instead. docs/netlist-spec.nets
    updated to match via a UUID-verified old-ref -> new-ref mapping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
